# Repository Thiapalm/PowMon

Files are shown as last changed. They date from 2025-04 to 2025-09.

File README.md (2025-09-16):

# (PowMon) Power Monitor Board

<p align=center>
 
 
</p>

This is a hobby development board conceived for usage in my home lab. The device monitors both a shunt  voltage drop and bus supply voltage. Programmable calibration value, conversion times, and averaging,  combined with an internal multiplier, enable direct readouts of current in amperes and power in watts.

The board has 2 headers used for address configuration, allowing all 16 addresses to be used as you see fit. The board power is provided by the I²C connector, and it can be used in 5V or 3V3 modes. 

## License and certification

This is an open source hardware project licensed under CERN-OHL-P. More details on [LICENSE.md](./LICENSE.md).  

## Project

The PCB project was developed in Kicad 9, all necessary project files are available in this repository and can be used freely, according to License.

## Board specifications

The board is based on the [**INA226**](https://www.ti.com/lit/gpn/ina226) from Texas Instruments.  
Board features commonly used in Embedded Systems:
- Measure voltages from 0V up to 36V
- Configurable averaging options
- Reports current, voltage and power
- I²C serial communication (Two Headers for BUS usage)
- LED indicators (LOAD, Board POWER and ALERT)
- 2.7v up to 5v operation voltage from I²C header
- Board Address selector (A0 and A1)

## Board View 

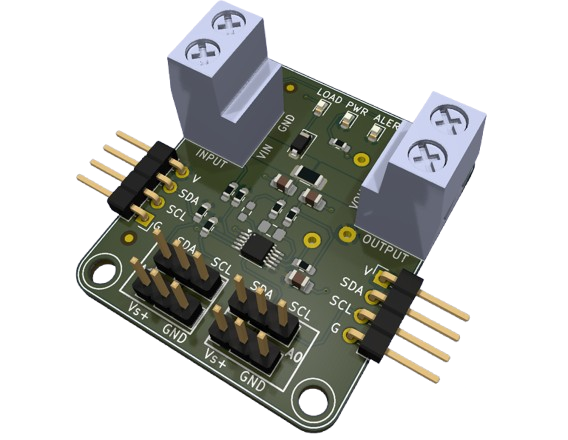
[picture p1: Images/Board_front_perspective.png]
Front


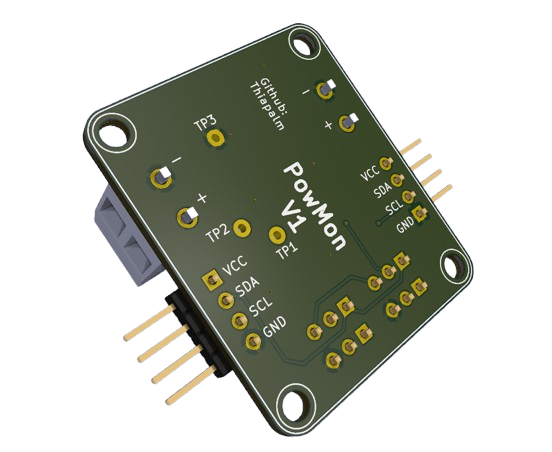
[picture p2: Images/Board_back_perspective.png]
Back


## Board Enclosure 

There is an enclosure made in Freecad 1.0 available on the enclosure folder, it can be used or modified as you see fit. For best results I recommend to print in transparent filament. You will also need 4 M3 x 10mm screws (black with flat head are recommended).  

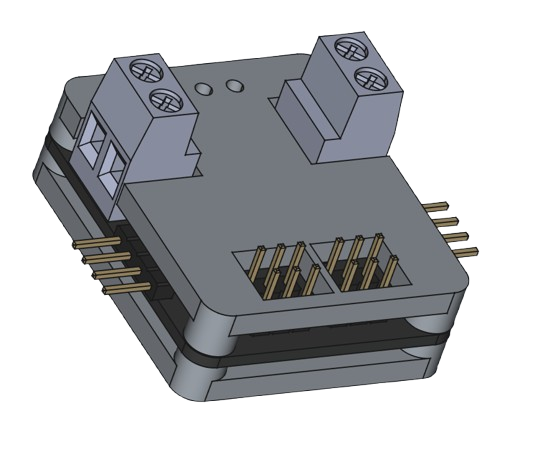
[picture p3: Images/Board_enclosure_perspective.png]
Enclosure

  
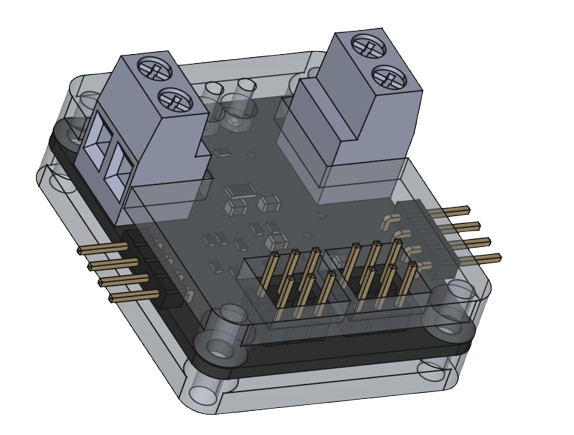
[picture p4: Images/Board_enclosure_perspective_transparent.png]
Transparent


## Version Revision

V1 - current version  
   - Added two I²C headers so it can be used in a bus
   - Added Address configuration headers
   - Added informational LEDs

## Firmware

There is no specific firmware for this board, but i have a driver (crate) developed in RUST for INA226, see it in [crates.io](https://crates.io/crates/ina226-tp) or you can search the internet for a c/c++ version.

## Contribution

Unless you explicitly state otherwise, any contribution intentionally submitted for inclusion in the work by you, as defined in the CERN-OHL-P license, shall be licensed as above, without any additional terms or conditions.

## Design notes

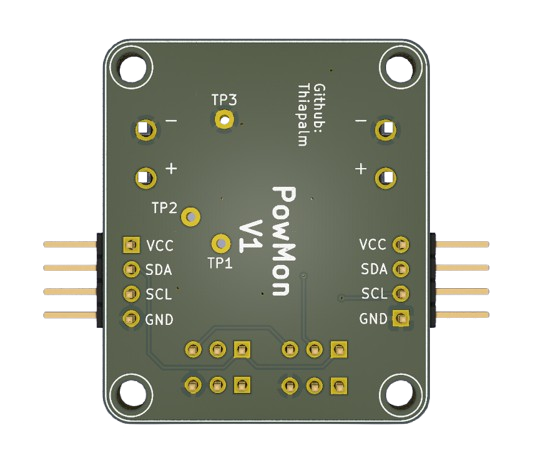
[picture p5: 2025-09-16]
Images/Board_back.png

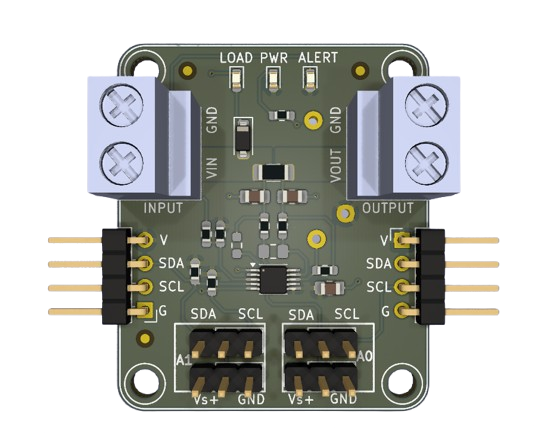
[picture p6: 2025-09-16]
Images/Board_front.png

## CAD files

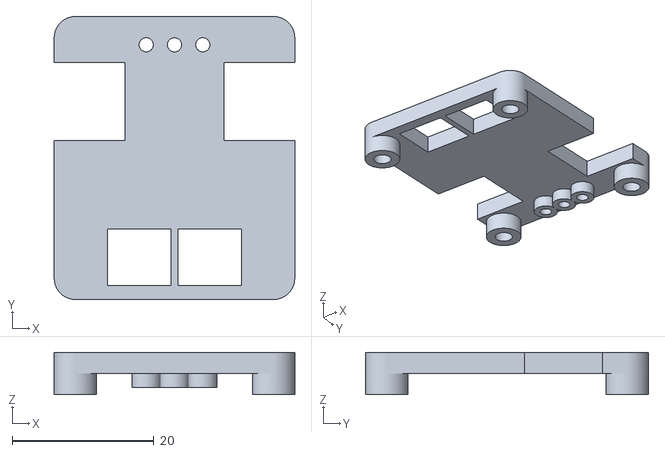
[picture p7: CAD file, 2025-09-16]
enclosure/PowMonBox-TopBody.stl
34.0 x 40.0 x 6.00

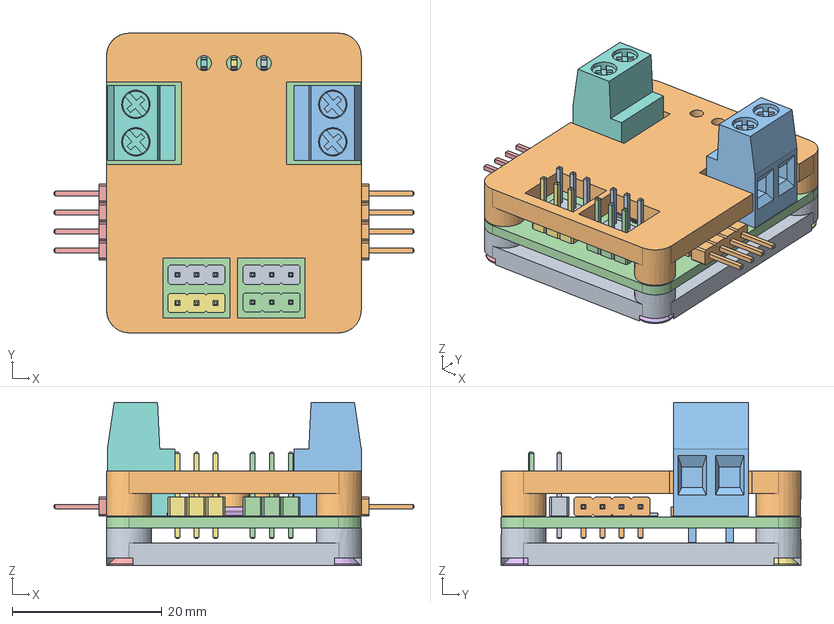
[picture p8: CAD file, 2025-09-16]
enclosure/PowMonBox.FCStd
48.1 x 40.0 x 21.8 mm
PinHeader_1x03_P2.54mm_Vertical
C_0805_2012Metric
R_0603_1608Metric
R_0603_1608Metric001
PinHeader_1x04_P2.54mm_Horizontal
R_0603_1608Metric002
R_1206_3216Metric
2 Way PCB Screw Terminal Block 5mm
LED_0603_1608Metric
R_0603_1608Metric003
2 Way PCB Screw Terminal Block 5mm001
R_0603_1608Metric004
R_0603_1608Metric005
C_0805_2012Metric001
PinHeader_1x03_P2.54mm_Vertical001
LED_0603_1608Metric001
PinHeader_1x03_P2.54mm_Vertical002
C_0805_2012Metric002
D_SOD-123
PinHeader_1x03_P2.54mm_Vertical003
R_0603_1608Metric006
VSSOP-10_3x3mm_P0.5mm
LED_0603_1608Metric002
R_0603_1608Metric007
R_0603_1608Metric008
PinHeader_1x04_P2.54mm_Horizontal001
C_0805_2012Metric003
PowMon_PCB
screw1
screw2
screw3
screw4
BottomBody
TopBody

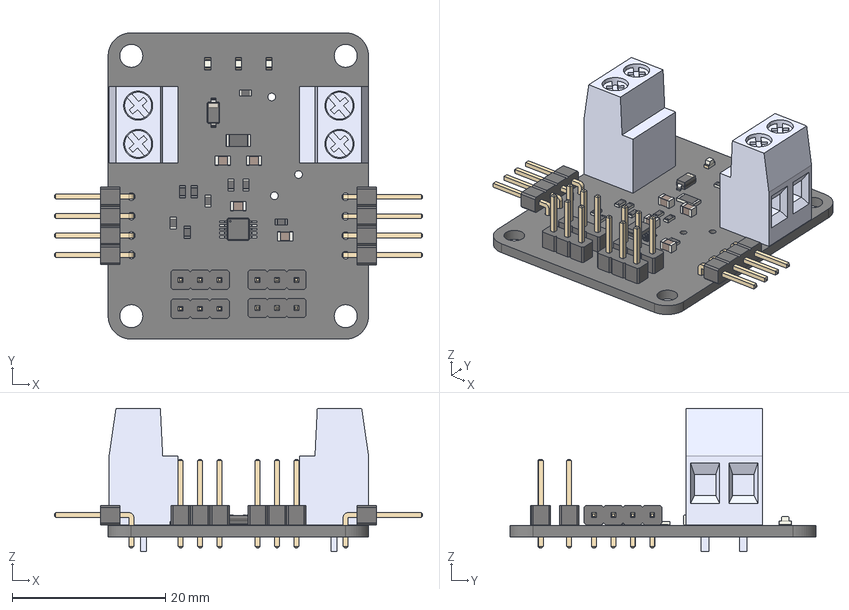
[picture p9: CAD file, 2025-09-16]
STEP/PowMon.step
48.1 x 40.0 x 18.7 mm
PinHeader_1x03_P2.54mm_Vertical x 4
C_0805_2012Metric x 4
R_0603_1608Metric x 9
PinHeader_1x04_P2.54mm_Horizontal x 2
R_1206_3216Metric
2 Way PCB Screw Terminal Block 5mm x 2
LED_0603_1608Metric x 3
D_SOD-123
VSSOP-10_3x3mm_P0.5mm
PowMon_PCB

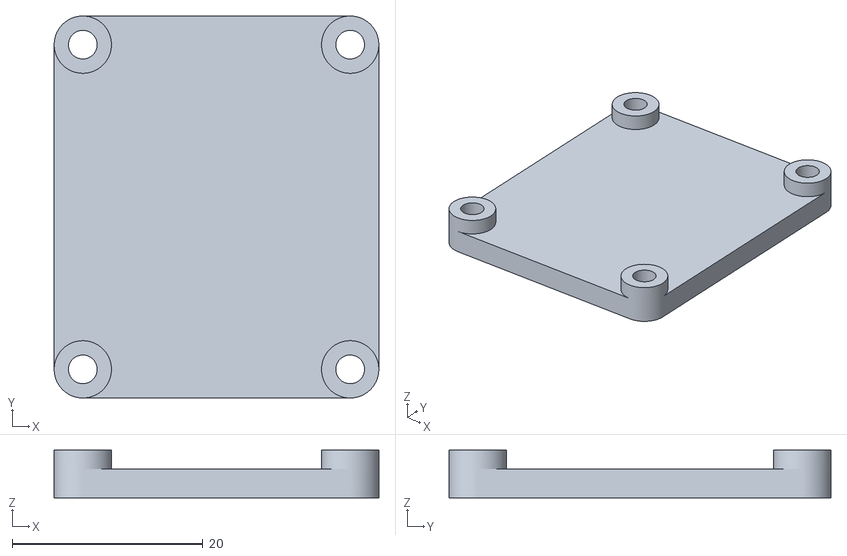
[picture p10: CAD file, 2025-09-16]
enclosure/PowMonBox-BottomBody.stl
34.0 x 40.0 x 5.00

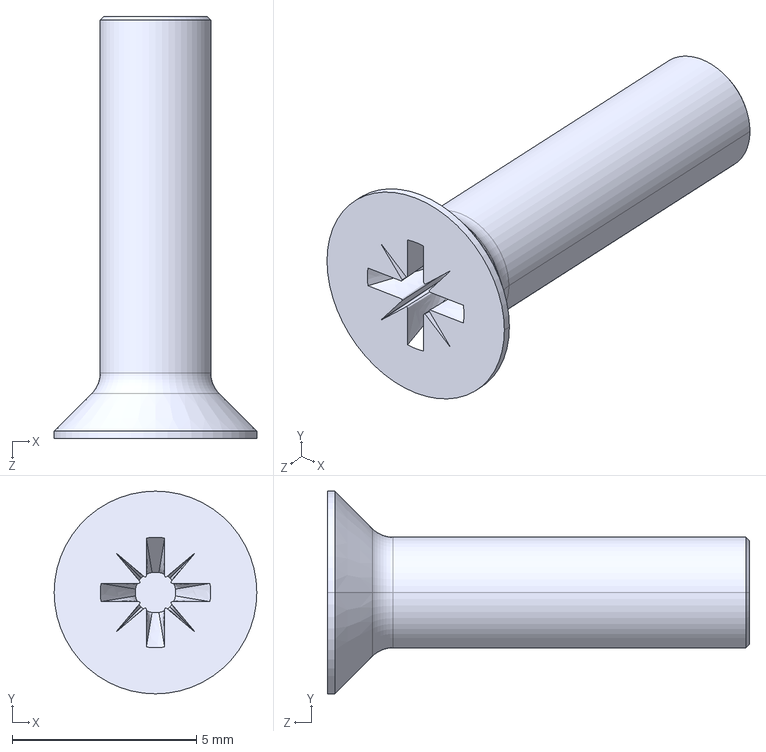
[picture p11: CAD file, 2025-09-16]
STEP/m3-10mm-screw.STEP
5.50 x 5.50 x 11.5 mm

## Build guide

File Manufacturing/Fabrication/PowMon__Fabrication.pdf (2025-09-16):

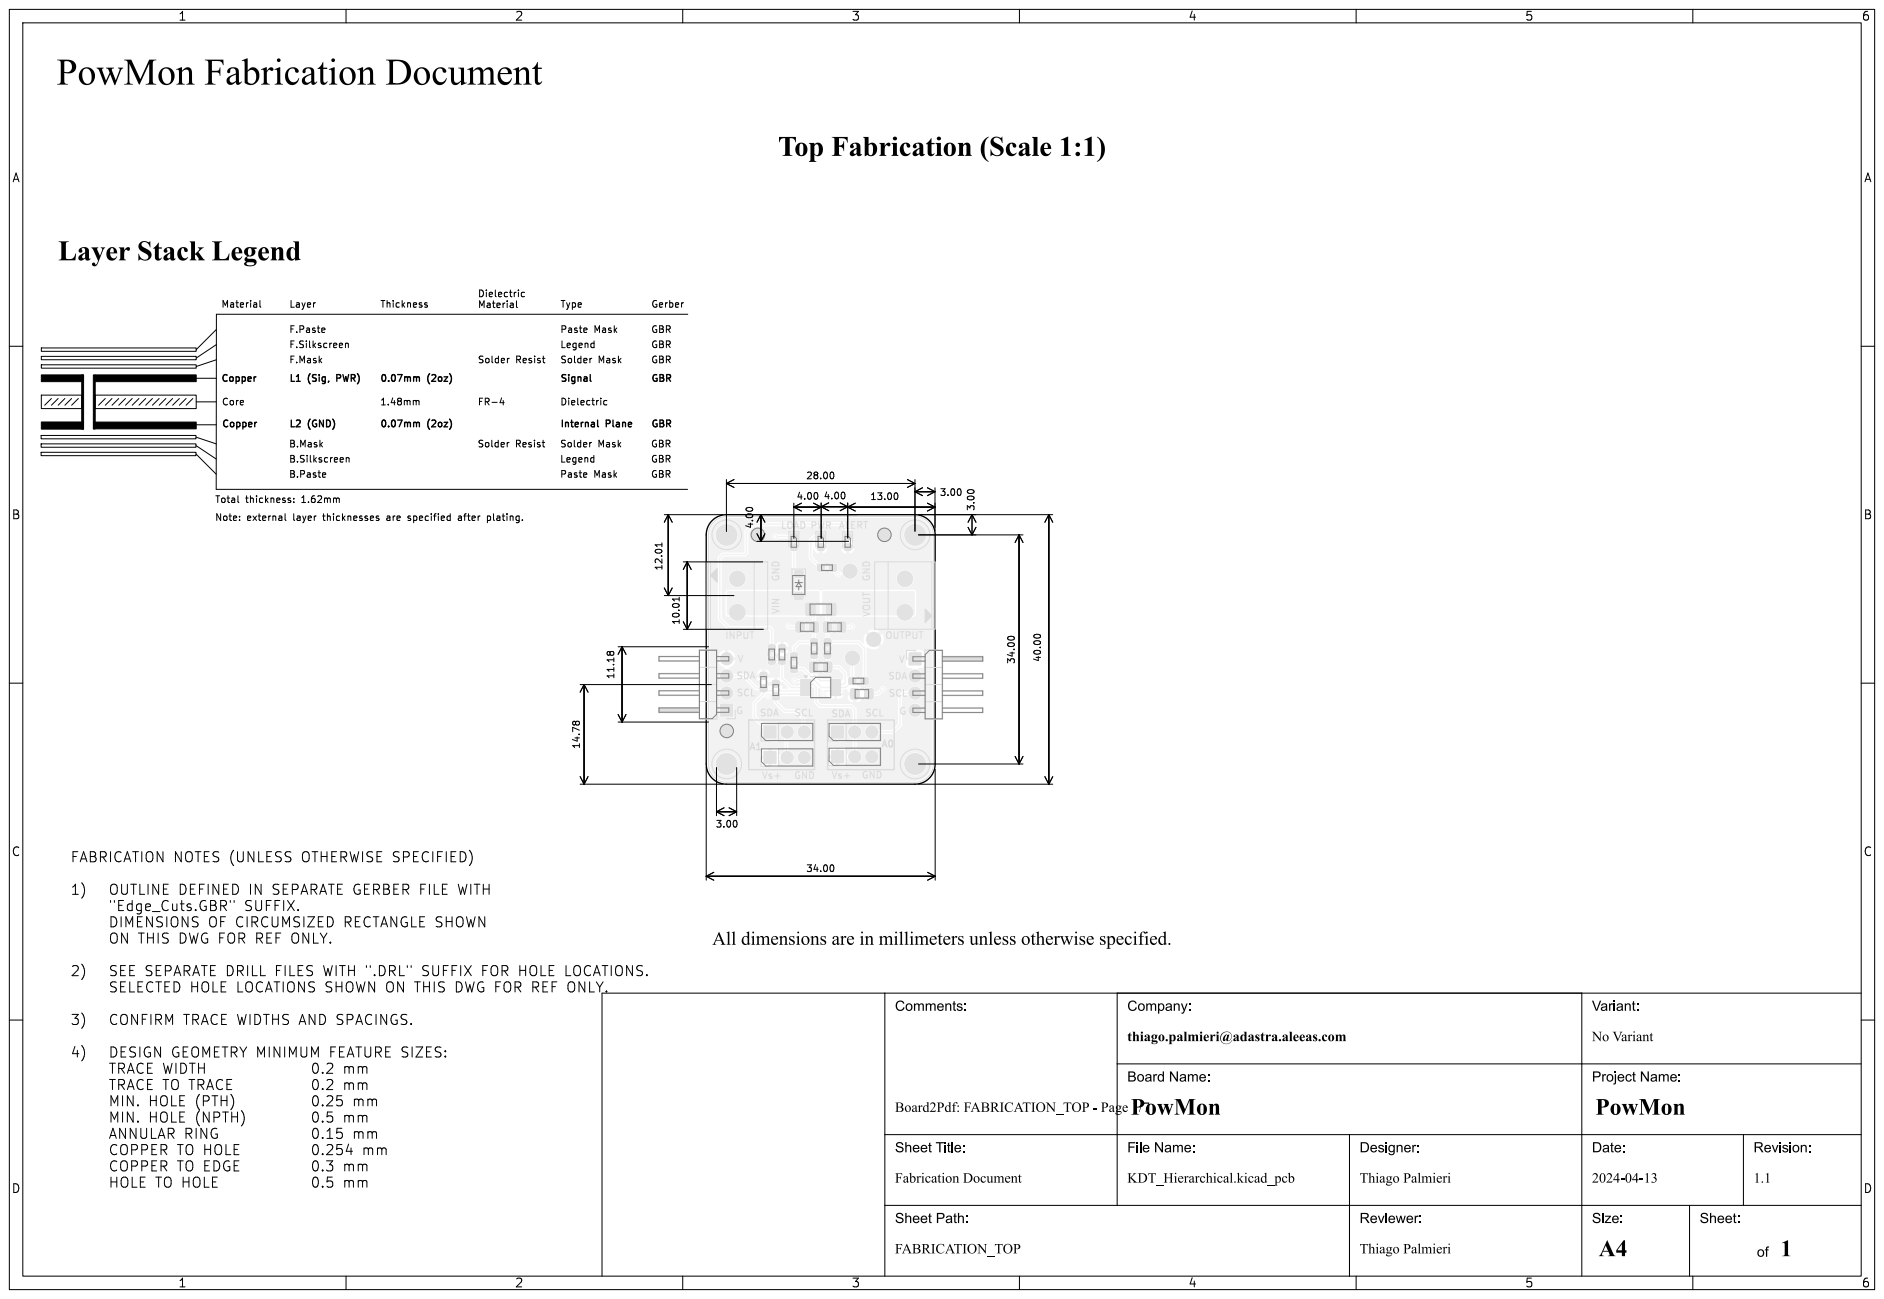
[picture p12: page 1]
LOAD; SCL; A0SDA GND; GND; INPUT SCL; VOUT GND; SDA; Vs+ PWR; SCL ALERT V; VIN; OUTPUT SCL GBR GBR; Total thickness:; Material; FR-4 Solder Resist; GBR; Legend FABRICATION; NOTES (UNLESS OTHERWISE SPECIFIED); 1) OUTLINE; DEFINED IN; SEPARATE; GERBER; FILE; WITH; "Edge_Cuts.GBR"; SUFFIX. DIMENSIONS; OF CIRCUMSIZED; RECTANGLE SHOWN ON; THIS; DWG; FOR; REF ONLY. 2) SEE; DRILL; FILES; ".DRL"; SUFFIX; HOLE LOCATIONS. SELECTED; HOLE; LOCATIONS SHOWN ON; REF ONLY. 3) CONFIRM; TRACE; WIDTHS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

Sheet Path: FabricationDocument Comments: Board2Pdf:FABRICATION_TOP- Page1/7 PowMonFabricationDocument

thiago.palmieri@adastra.aleeas.com

Revision: 1.1 Date: Project Name: 2024-04-13 Reviewer: ThiagoPalmieri Designer:

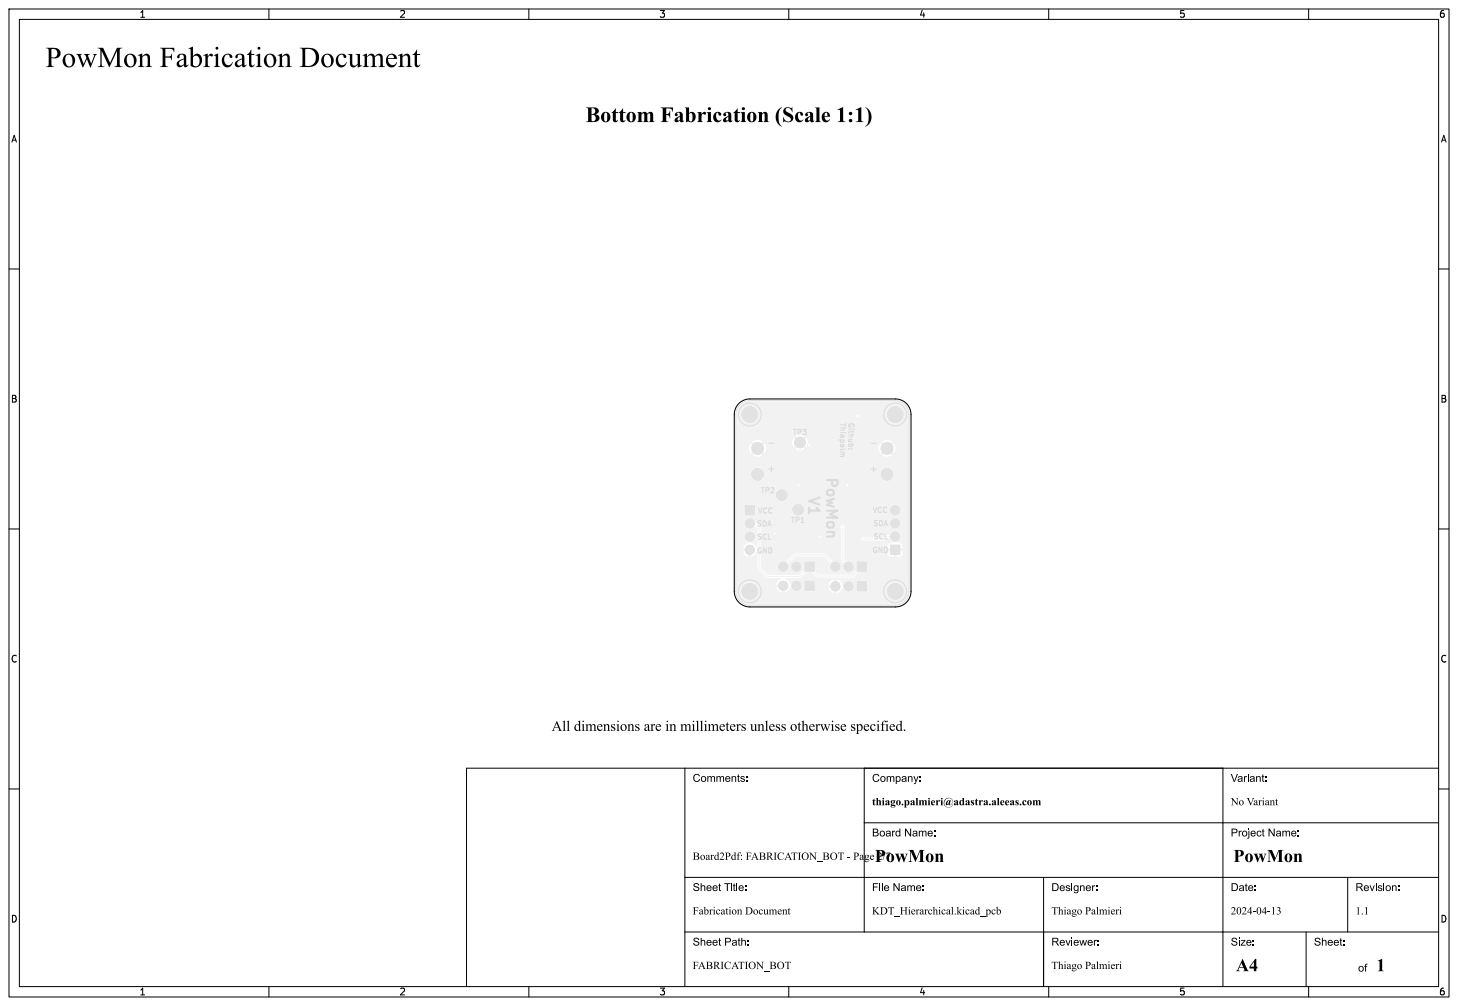
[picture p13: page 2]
SDA; VCC; GND; SCL SDA Thiapalm Github: SCL GND; PowMon; D Sheet: of 1; Size: A4; KDT_Hierarchical.kicad_pcb; ThiagoPalmieri Board Name:; Variant: No Variant Company:; Sheet Title:; File Name: FABRICATION_BOT Sheet Path: FabricationDocument Comments: Board2Pdf:FABRICATION_BOT- Page2/7 PowMonFabricationDocument

thiago.palmieri@adastra.aleeas.com

Revision: 1.1 Date: Project Name: 2024-04-13 Reviewer: ThiagoPalmieri Designer:

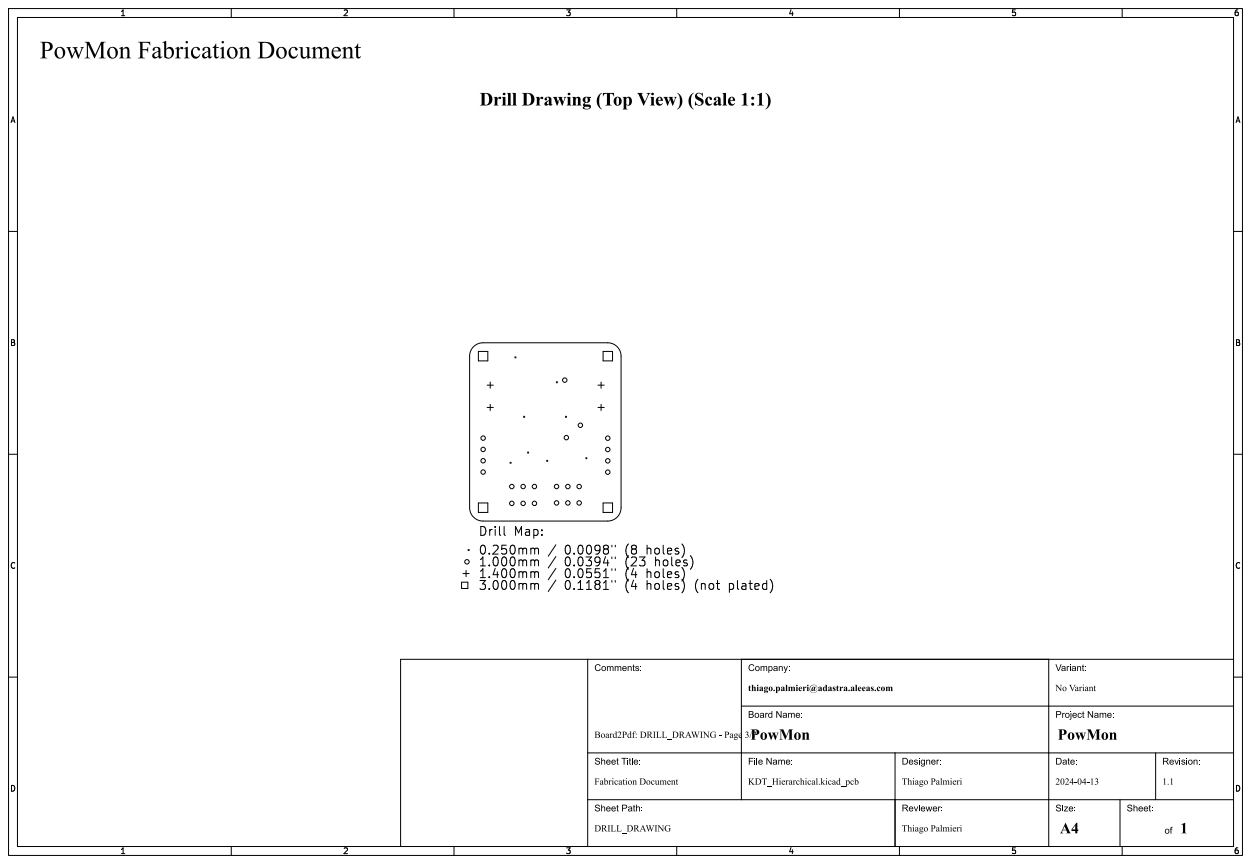
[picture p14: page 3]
D Sheet: of 1; Size: A4; KDT_Hierarchical.kicad_pcb; ThiagoPalmieri Board Name:; Variant: No Variant Company:; PowMon; Sheet Title:; File Name: DRILL_DRAWING

Sheet Path: FabricationDocument Comments: Board2Pdf:DRILL_DRAWING - Page3/7 PowMonFabricationDocument

thiago.palmieri@adastra.aleeas.com

Revision: 1.1 Date: Project Name: 2024-04-13 Reviewer: ThiagoPalmieri Designer:

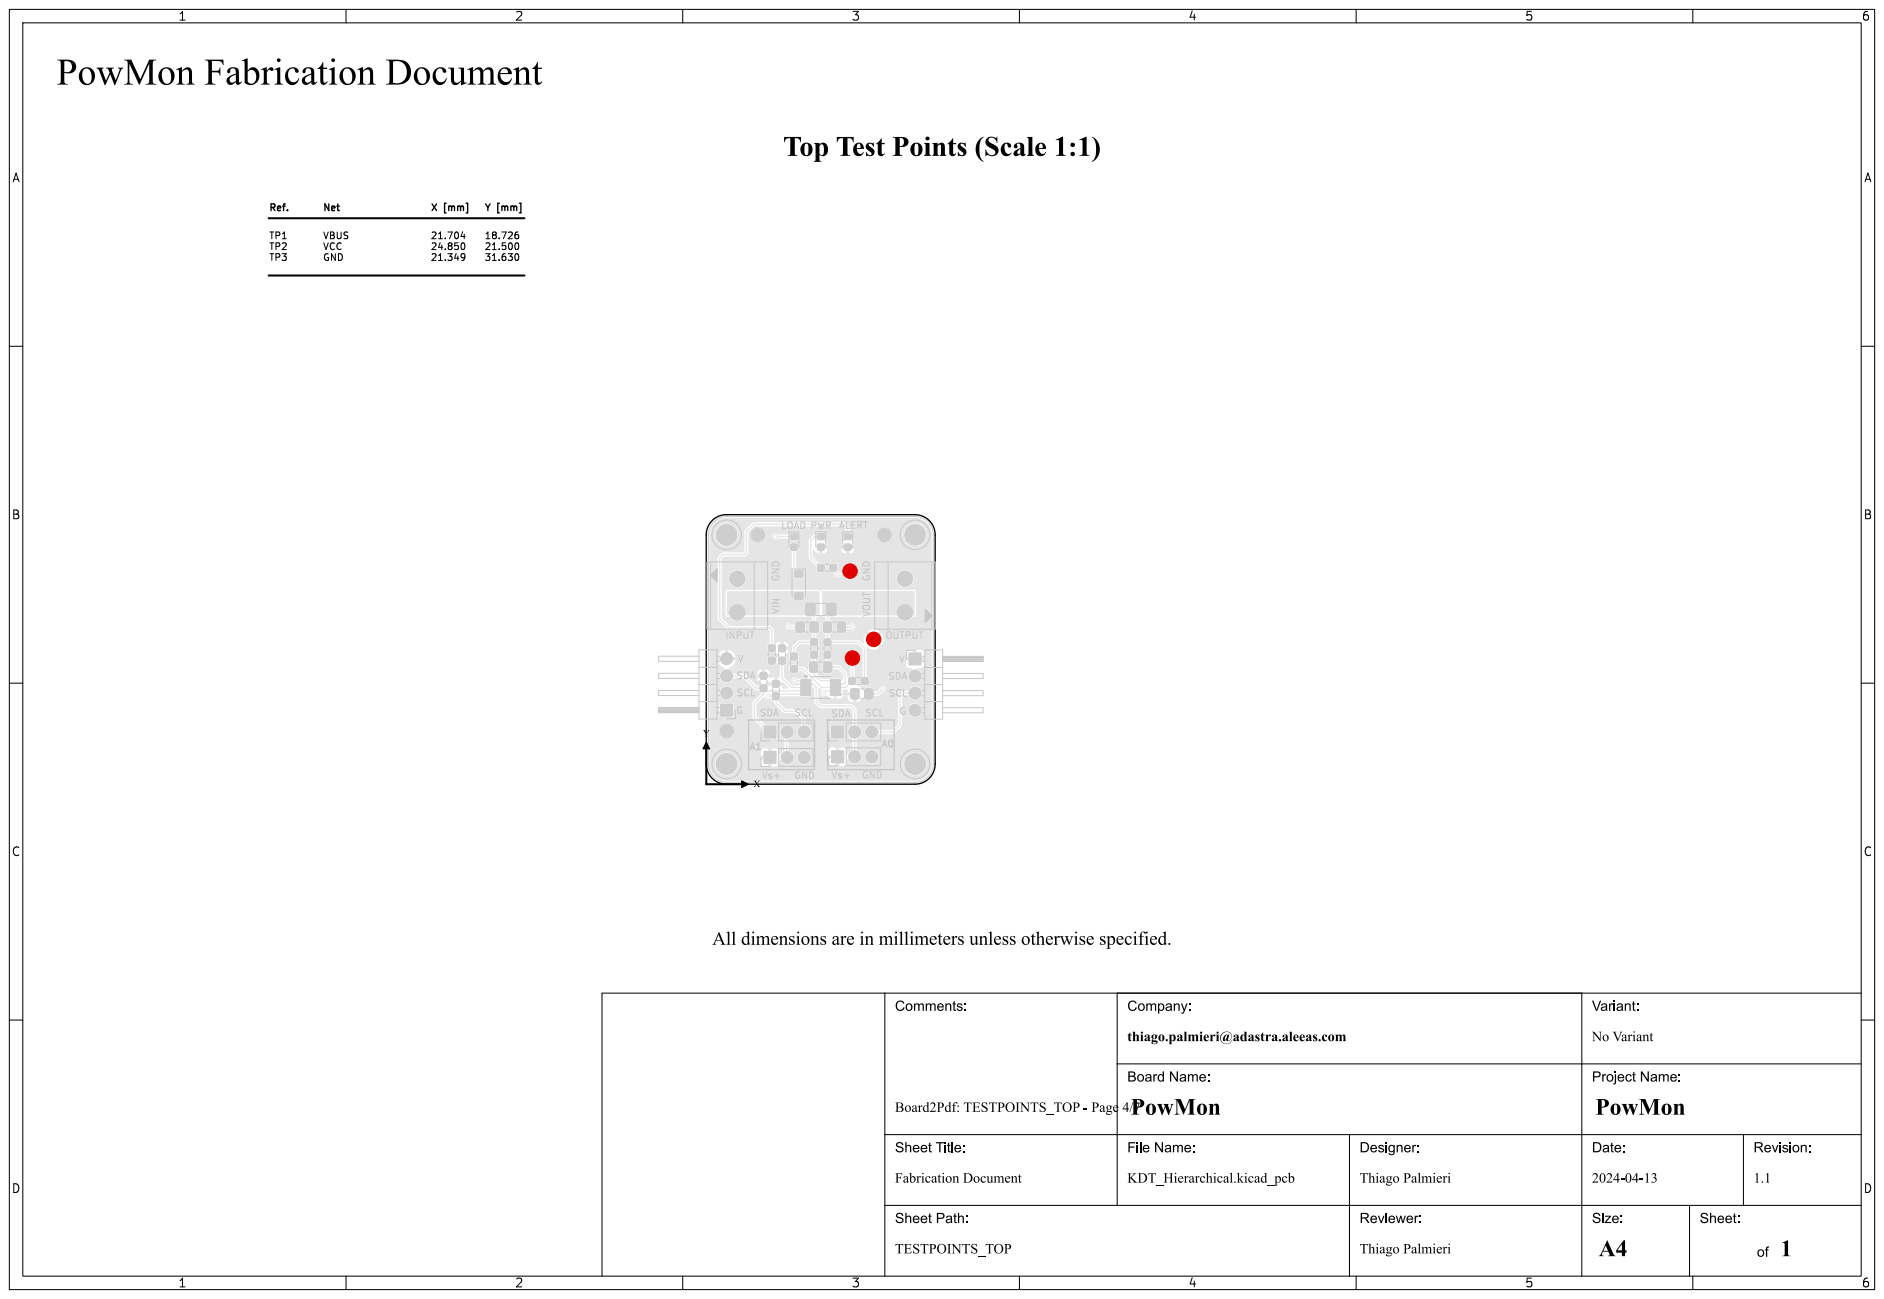
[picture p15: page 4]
LOAD; SCL; A0SDA GND; GND; INPUT SCL; VOUT GND; SDA; Vs+ PWR; SCL ALERT V; VIN; OUTPUT SCL; VBUS VCC GND; 31.630 Ref.; 21.349 Net; D Sheet: of 1; Size: A4; KDT_Hierarchical.kicad_pcb; ThiagoPalmieri Board Name:; Variant: No Variant Company:; PowMon; Sheet Title:; File Name: TESTPOINTS_TOP

Sheet Path: FabricationDocument Comments: Board2Pdf:TESTPOINTS_TOP- Page4/7 PowMonFabricationDocument

thiago.palmieri@adastra.aleeas.com

Revision: 1.1 Date: Project Name: 2024-04-13 Reviewer: ThiagoPalmieri Designer:

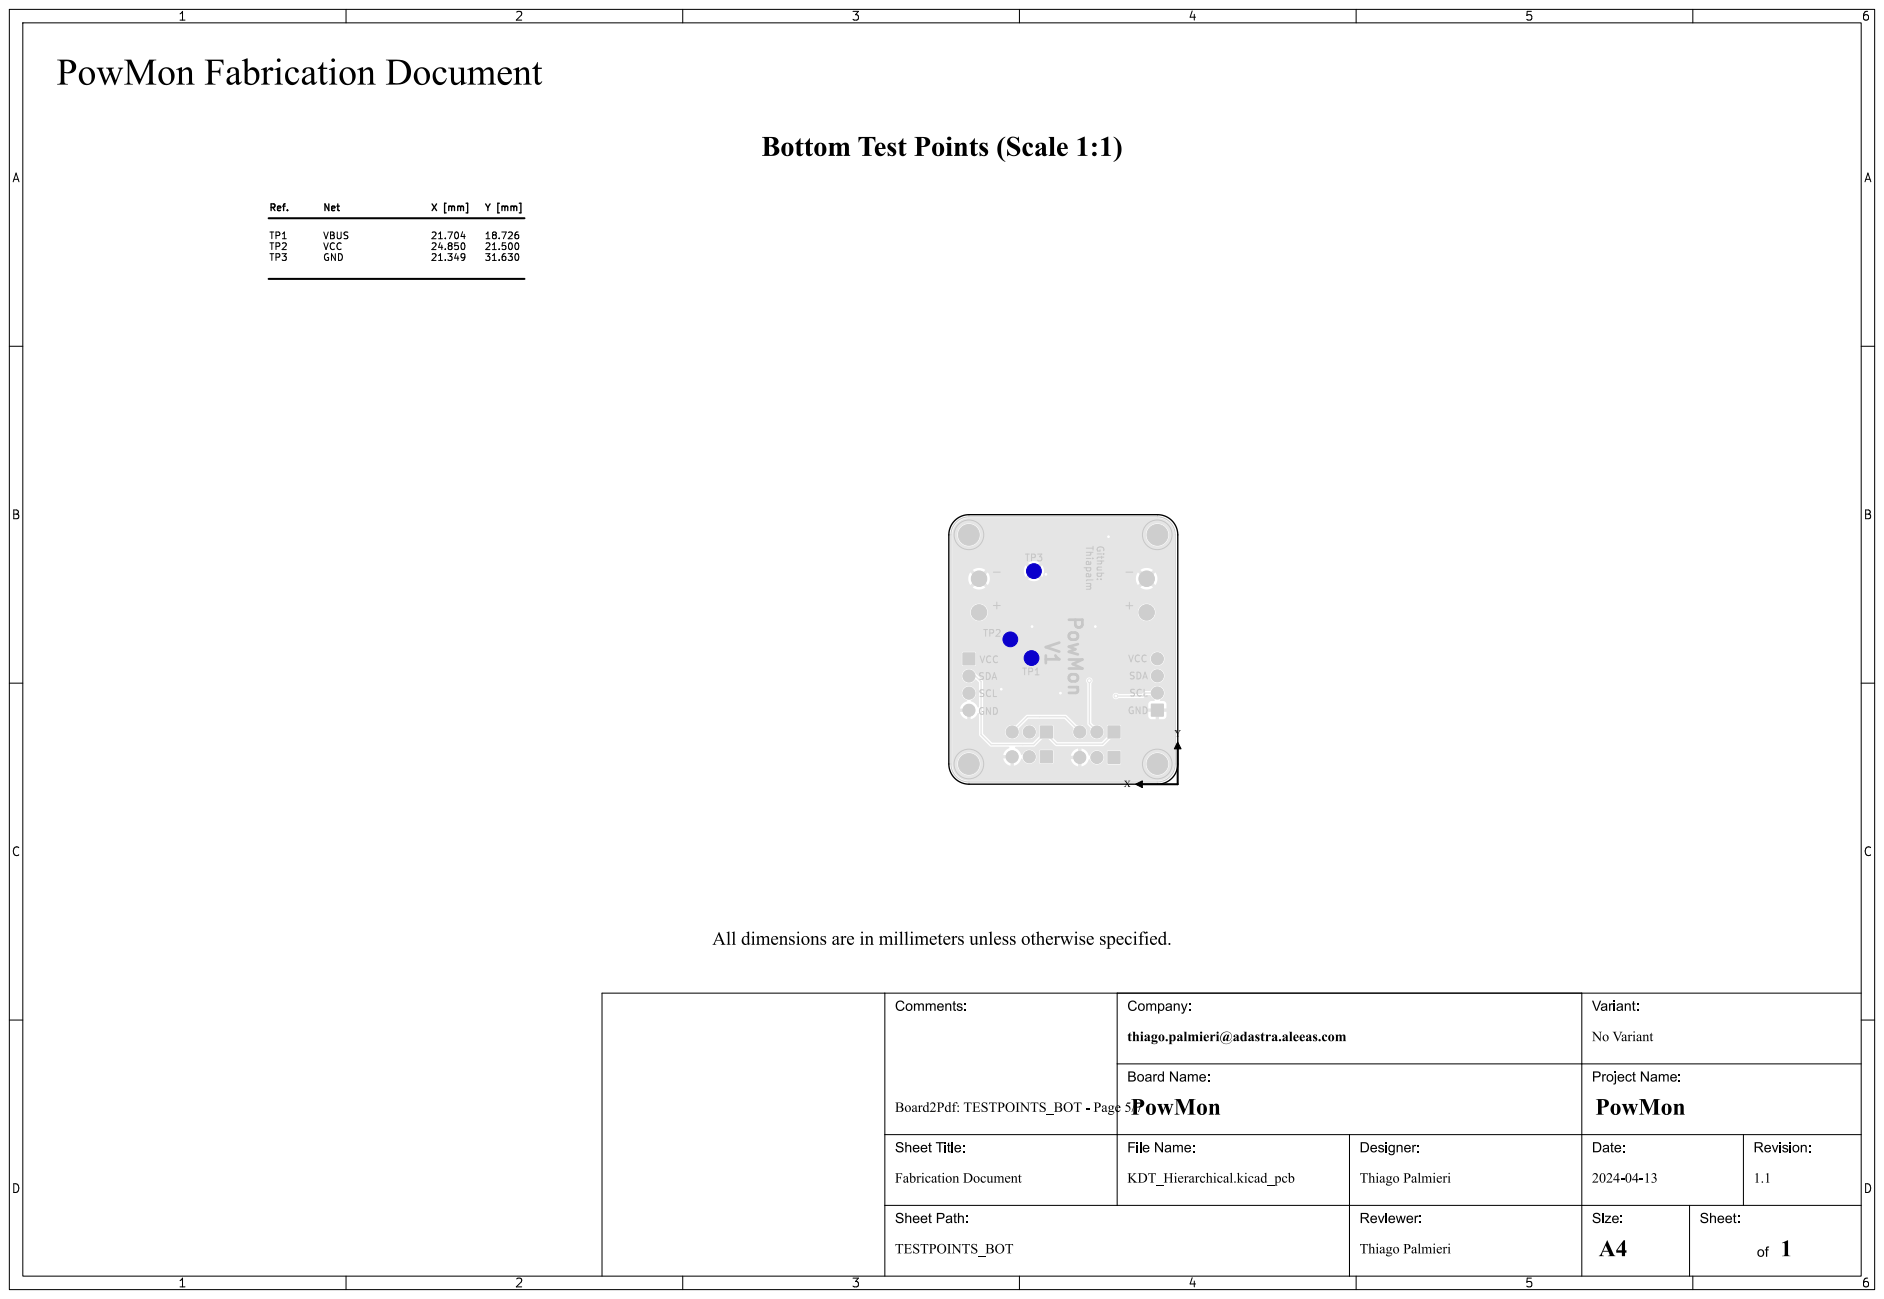
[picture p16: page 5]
SDA; VCC; GND; SCL SDA Thiapalm Github: SCL GND; PowMon; VBUS VCC GND; Net; 31.630 Ref. 1; D Sheet: of 1; Size: A4; KDT_Hierarchical.kicad_pcb; ThiagoPalmieri Board Name:; Variant: No Variant Company:; Sheet Title:; File Name: TESTPOINTS_BOT Sheet Path: FabricationDocument Comments: Board2Pdf:TESTPOINTS_BOT- Page5/7 PowMonFabricationDocument

thiago.palmieri@adastra.aleeas.com

Revision: 1.1 Date: Project Name: 2024-04-13 Reviewer: ThiagoPalmieri Designer:

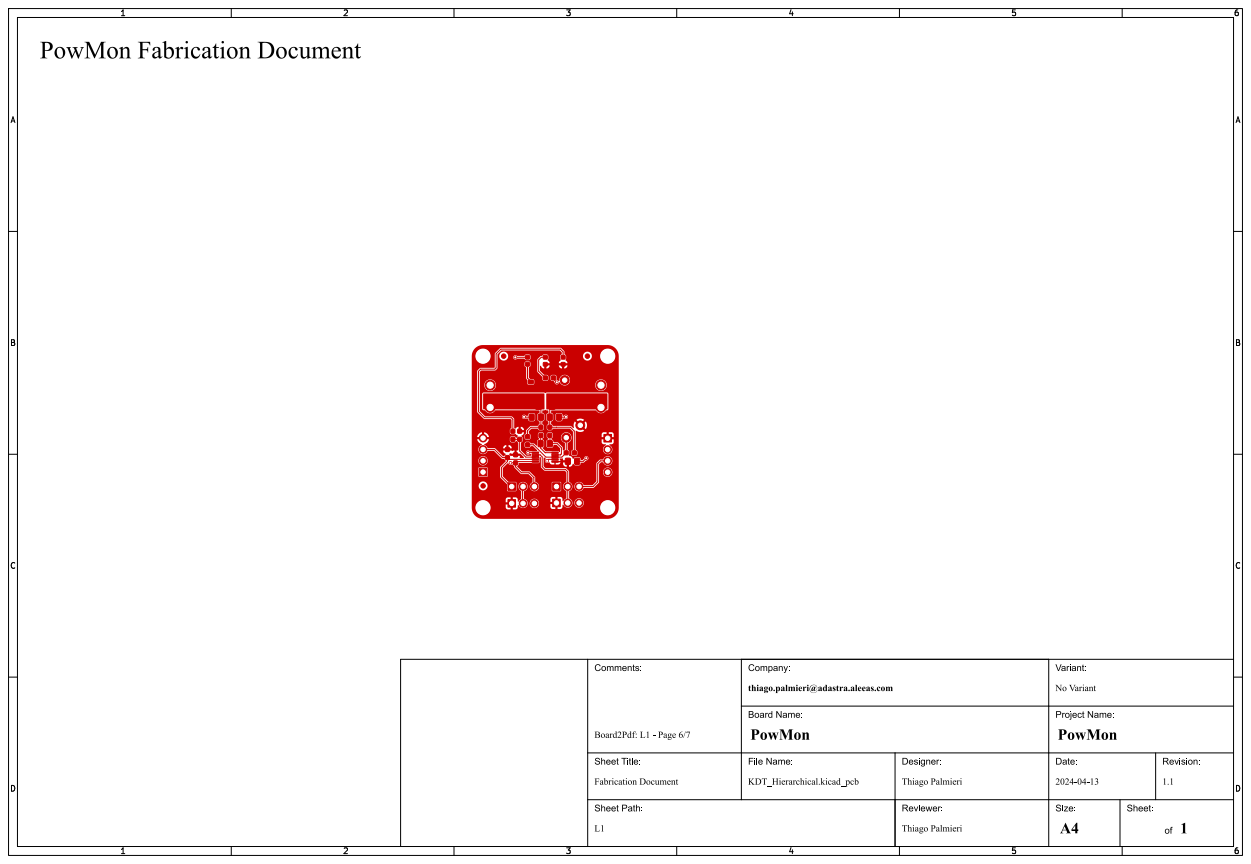
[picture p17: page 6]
D Sheet: of 1; Size: A4; KDT_Hierarchical.kicad_pcb; ThiagoPalmieri Board Name:; Variant: No Variant Company:; PowMon; Sheet Title:; File Name: L1Sheet Path: FabricationDocument Comments: Board2Pdf:L1 - Page6/7 PowMonFabricationDocument

thiago.palmieri@adastra.aleeas.com

Revision: 1.1 Date: Project Name: 2024-04-13 Reviewer: ThiagoPalmieri Designer:

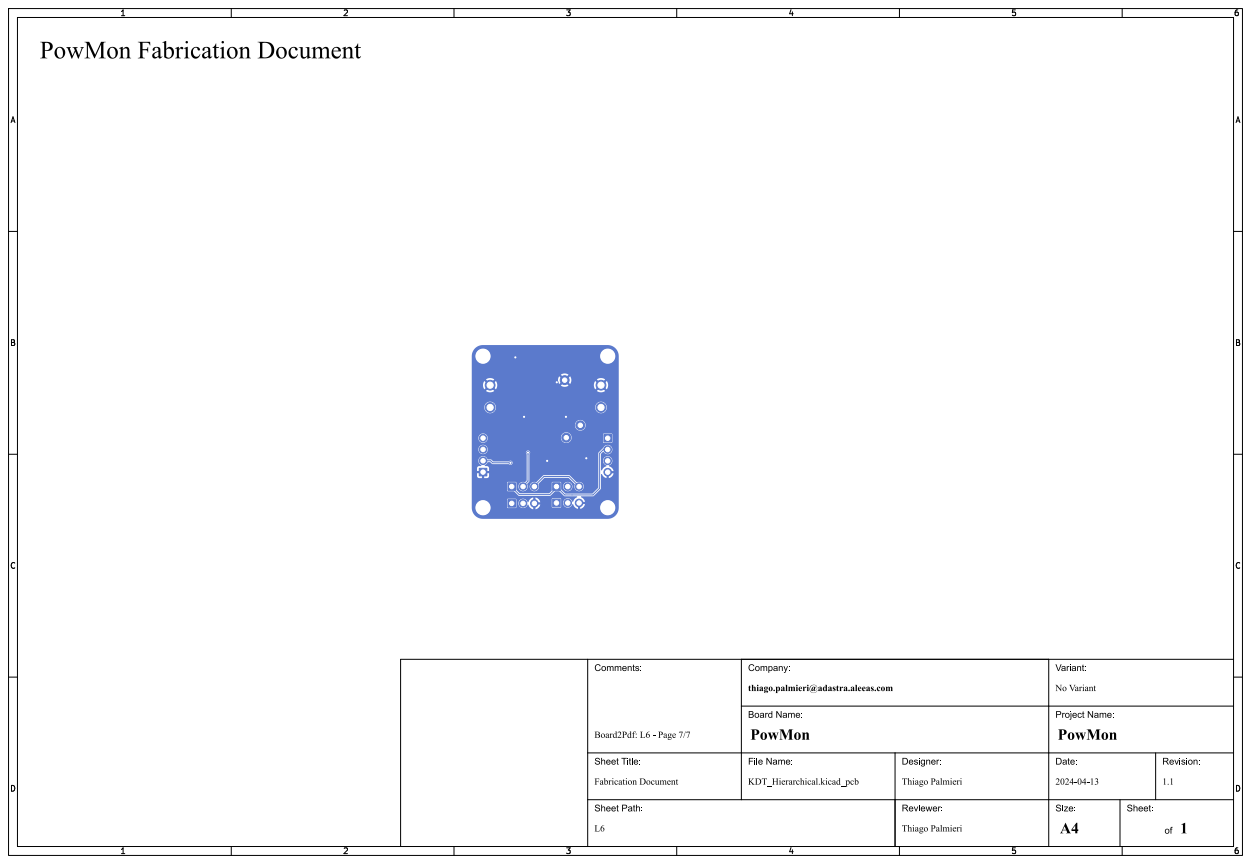
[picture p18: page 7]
D Sheet: of 1; Size: A4; KDT_Hierarchical.kicad_pcb; ThiagoPalmieri Board Name:; Variant: No Variant Company:; PowMon; Sheet Title:; File Name: L6Sheet Path: FabricationDocument Comments: Board2Pdf:L6 - Page7/7 PowMonFabricationDocument

thiago.palmieri@adastra.aleeas.com

Revision: 1.1 Date: Project Name: 2024-04-13 Reviewer: ThiagoPalmieri Designer:

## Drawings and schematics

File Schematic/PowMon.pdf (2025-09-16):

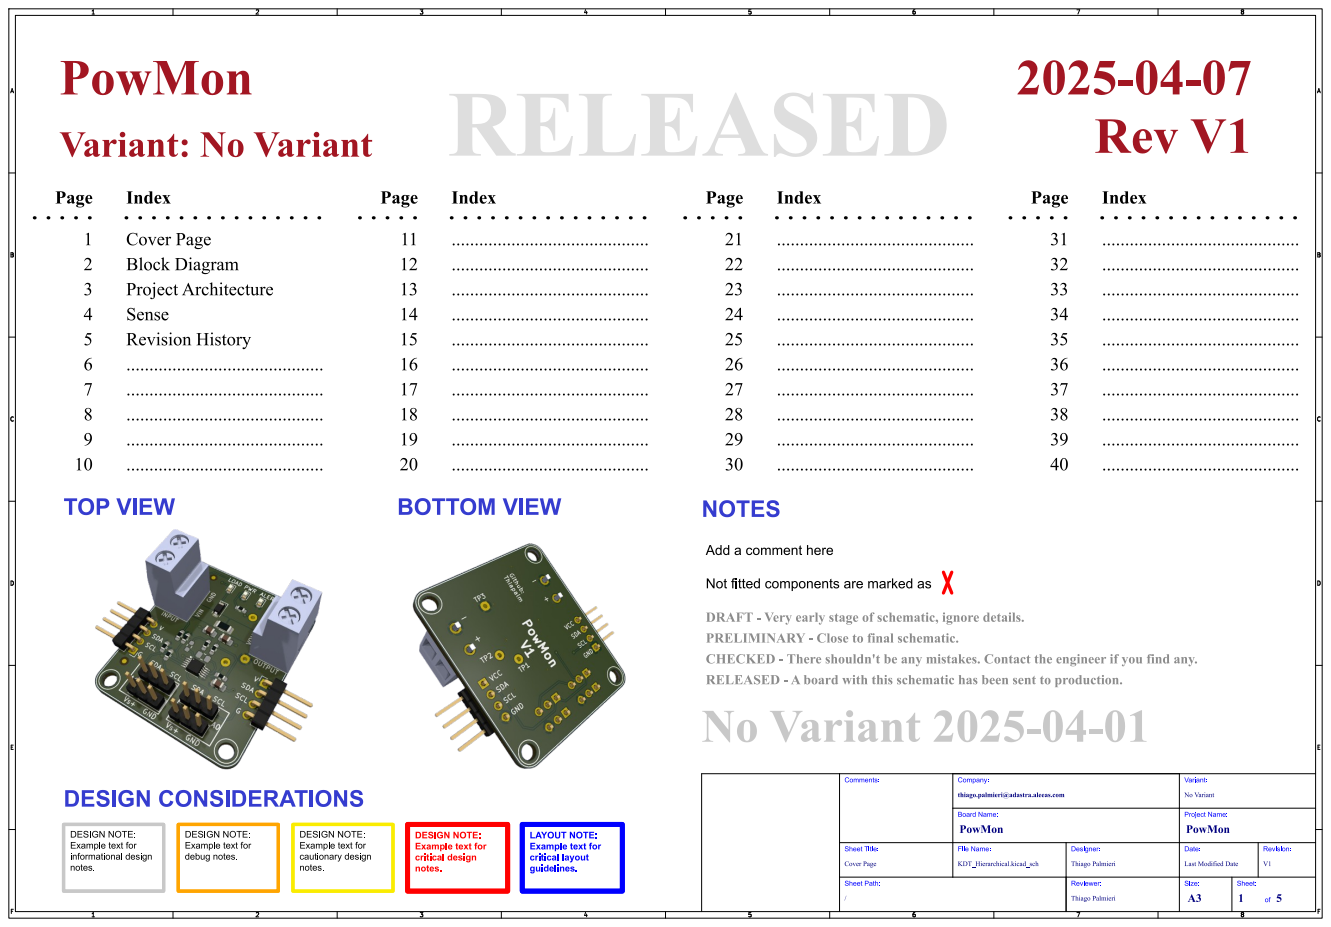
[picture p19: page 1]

Not fitted components are marked as

DRAFT - Veryearlystageof schematic,ignoredetails.
PRELIMINARY - Closetofinal schematic.
CHECKED - Thereshouldn'tbeanymistakes.Contacttheengineerif youfindany.
RELEASED - A boardwiththisschematichasbeensenttoproduction.
NoVariant2025-04-01

thiago.palmieri@adastra.aleeas.com

Revision: V1 Date: Project Name: LastModified Date Reviewer: ThiagoPalmieri Designer:

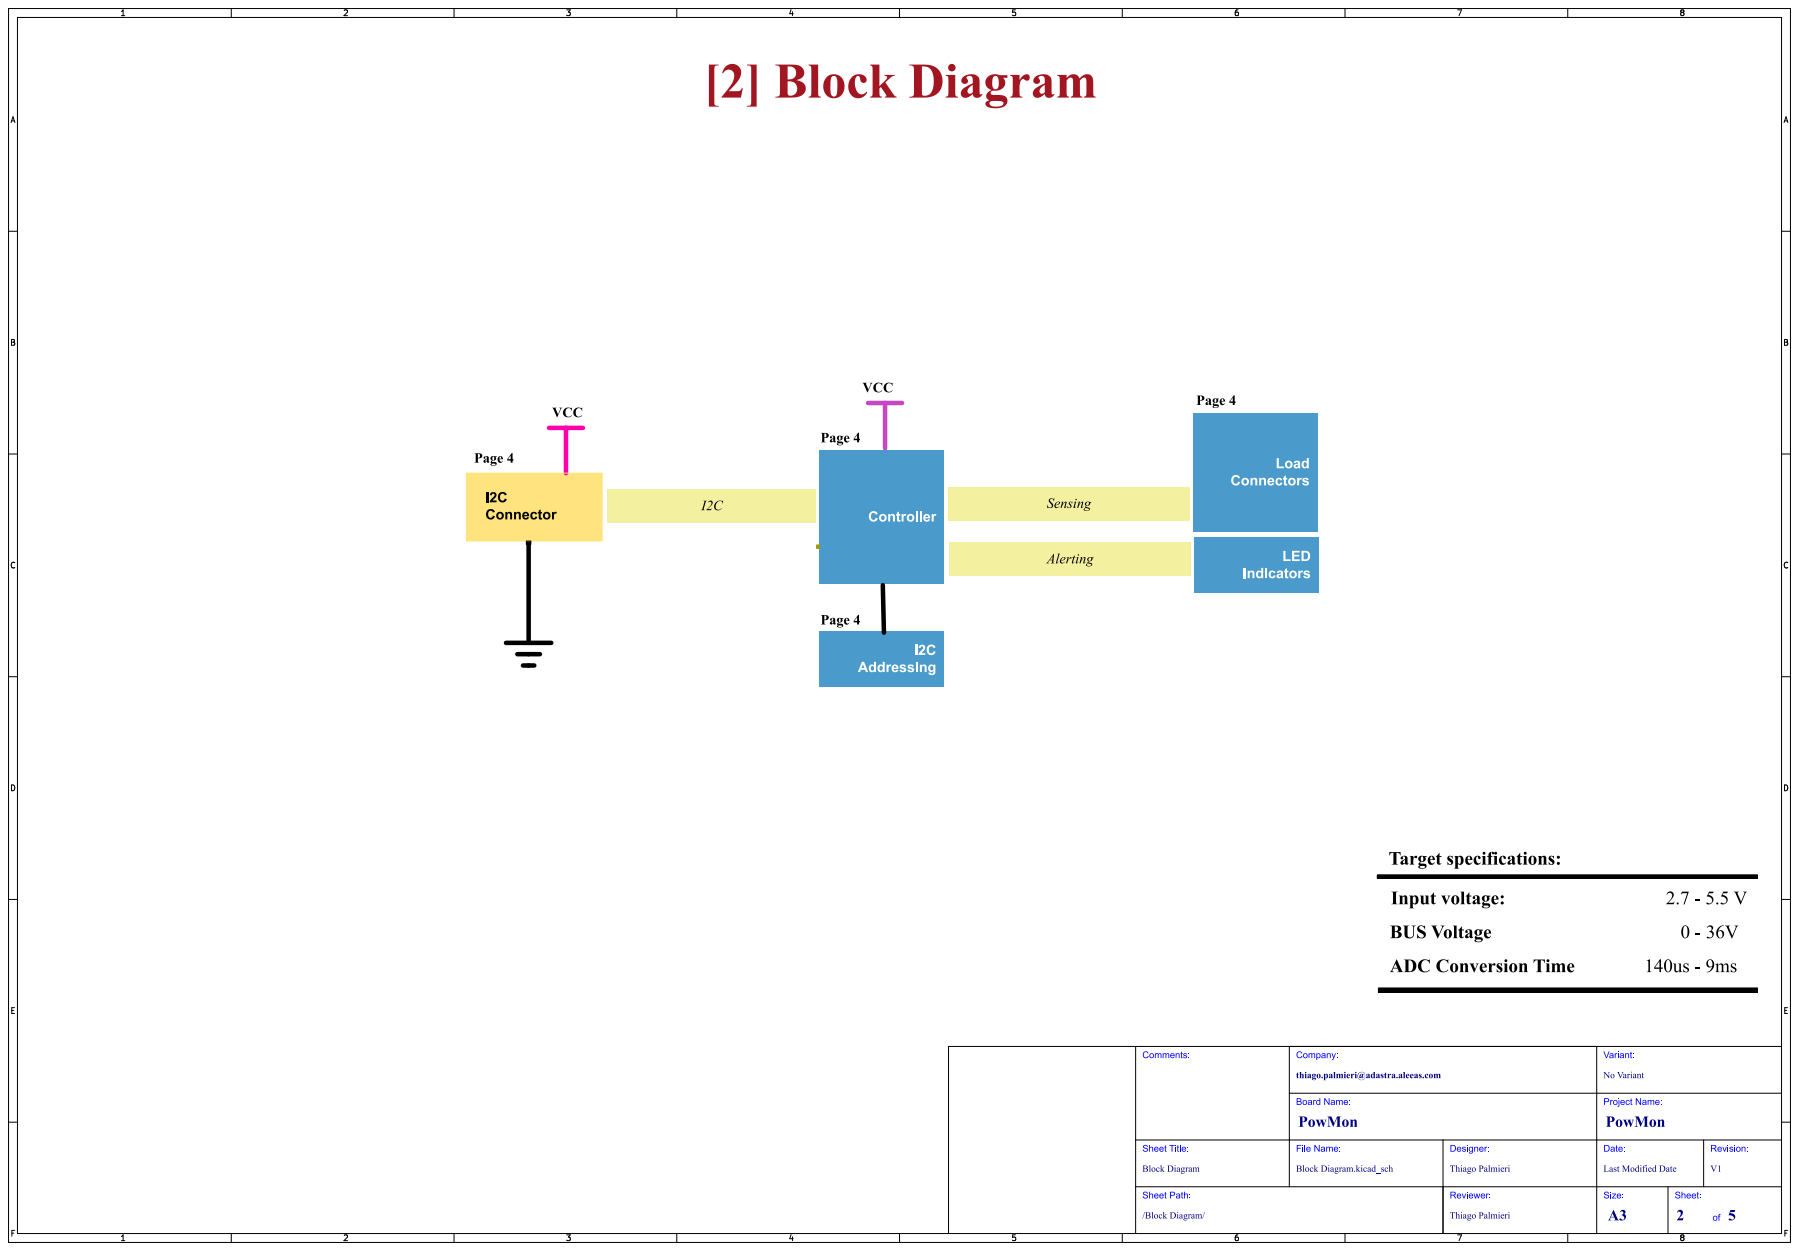
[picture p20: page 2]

thiago.palmieri@adastra.aleeas.com

/Block Diagram/ Sheet Path: Block Diagram

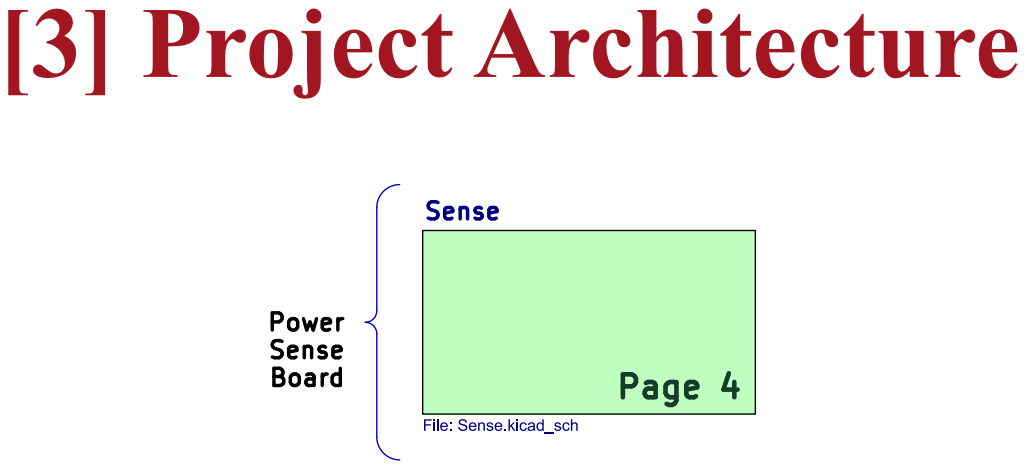
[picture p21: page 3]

/ProjectArchitecture/ Sheet Path: ProjectArchitecture Comments:

thiago.palmieri@adastra.aleeas.com

Revision: V1 Date: Project Name: LastModified Date Reviewer: ThiagoPalmieri Designer:

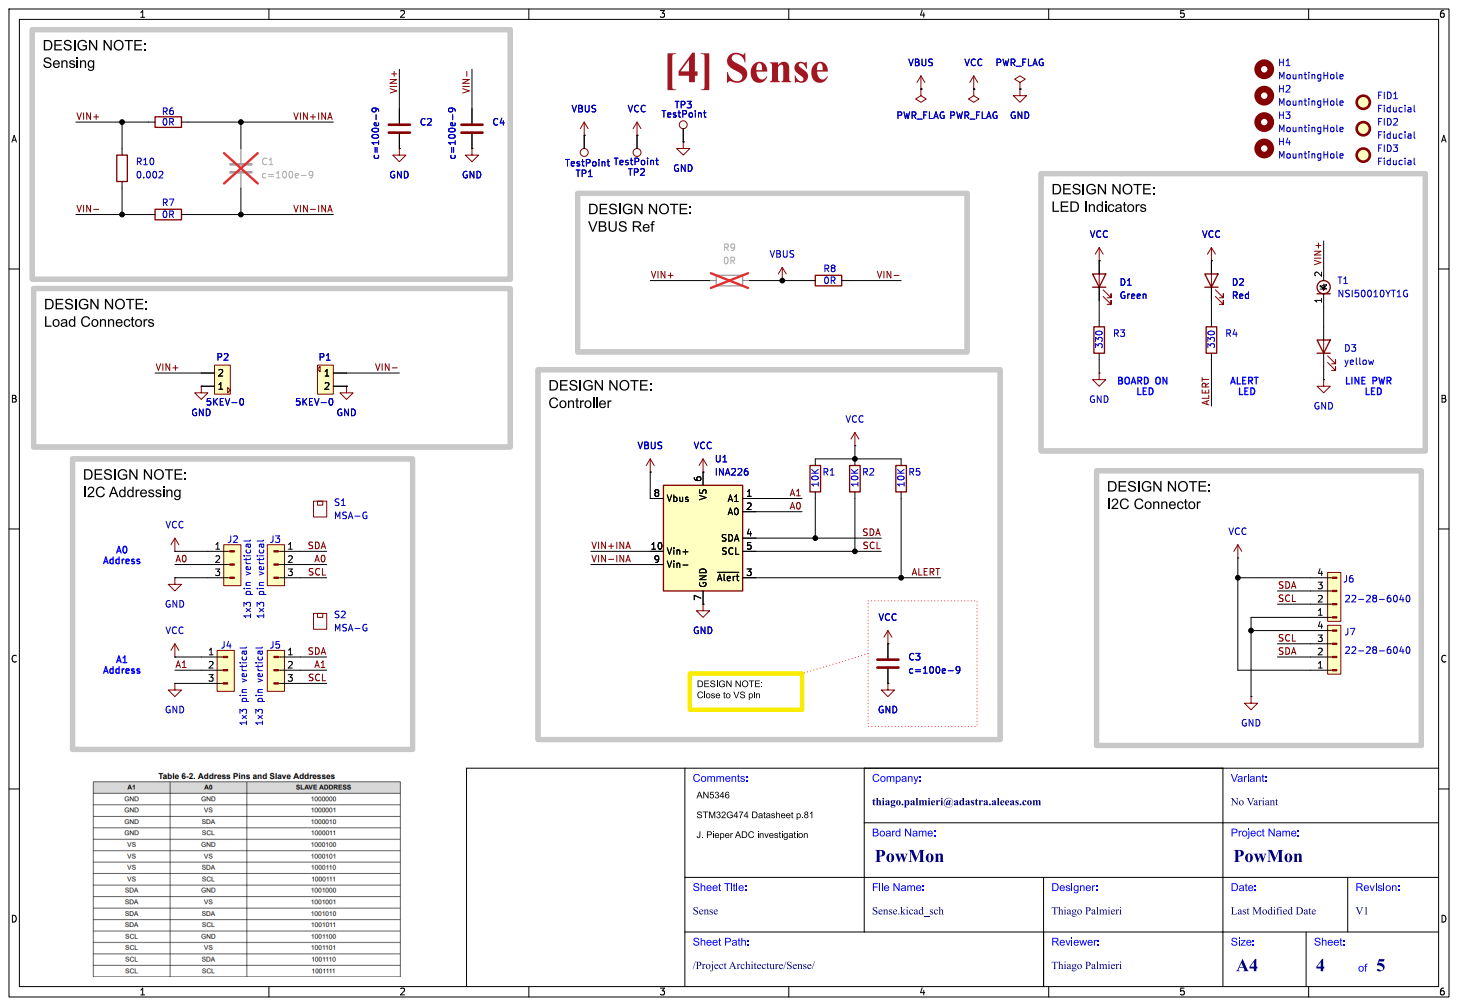
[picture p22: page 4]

7 A1 1 A0 2 SDA 4 SCL 5 ~{Alert}3 VCC GND

/ProjectArchitecture/Sense/ Sheet Path: Sense Comments:

thiago.palmieri@adastra.aleeas.com

Revision: V1 Date: Project Name: LastModified Date Reviewer: ThiagoPalmieri Designer:

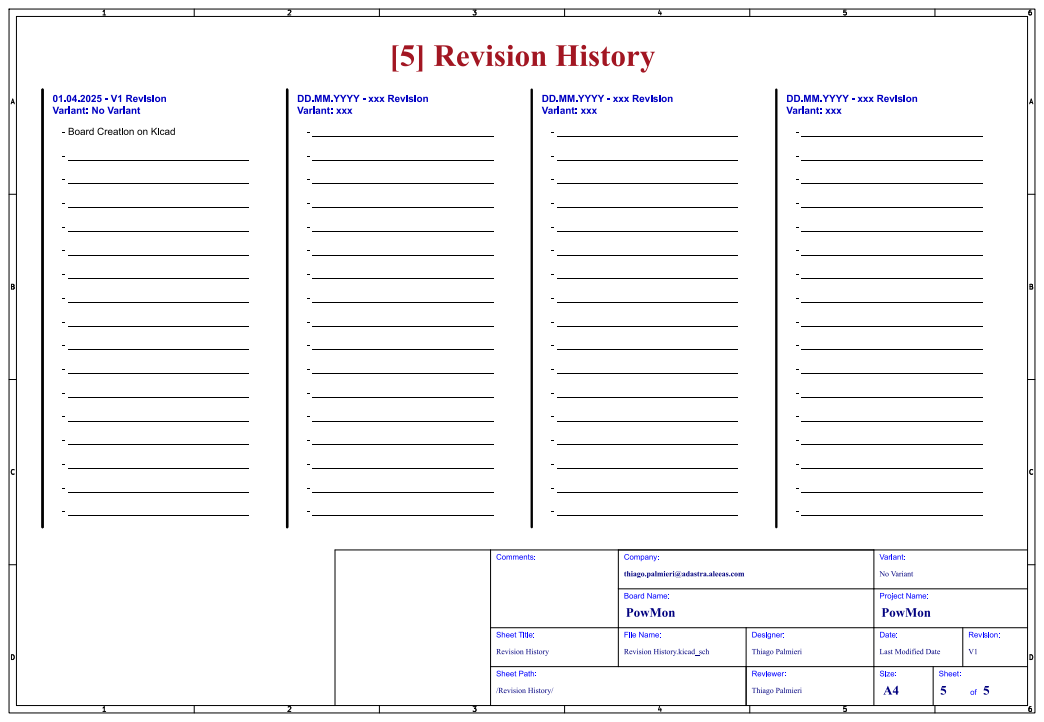
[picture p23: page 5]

01.04.2025 - V1 Revision
Variant: No Variant
- Board Creation on Kicad

Variant: xxx DD.MM.YYYY - xxx Revision

DD.MM.YYYY - xxx Revision

/RevisionHistory/ Sheet Path: RevisionHistory Comments:

thiago.palmieri@adastra.aleeas.com

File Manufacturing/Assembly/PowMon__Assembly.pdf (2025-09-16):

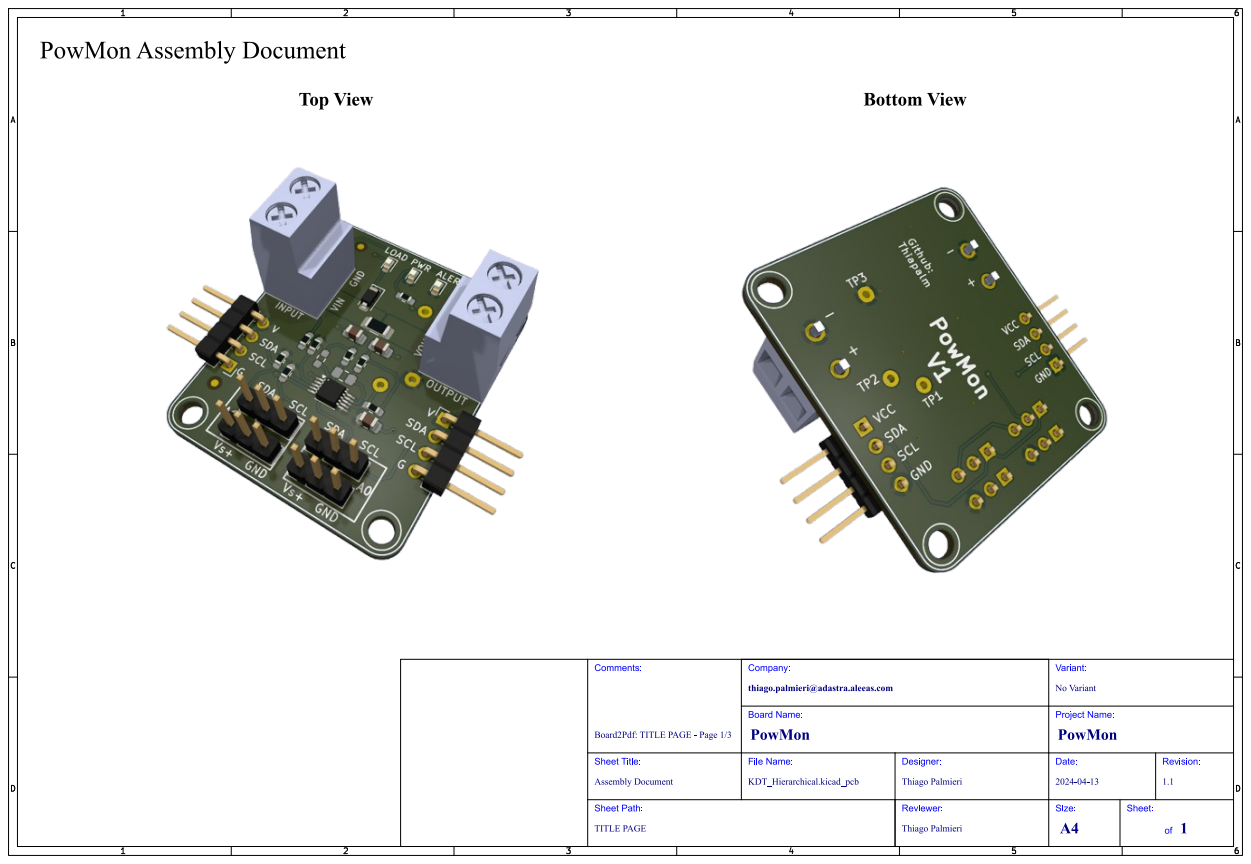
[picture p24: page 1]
D Sheet: of 1; Size: A4; KDT_Hierarchical.kicad_pcb; ThiagoPalmieri Board Name:; Variant: No Variant Company:; PowMon; Sheet Title:; File Name: TITLE PAGE

Sheet Path: AssemblyDocument Comments: Board2Pdf:TITLE PAGE- Page1/3 PowMonAssemblyDocument

thiago.palmieri@adastra.aleeas.com

Revision: 1.1 Date: Project Name: 2024-04-13 Reviewer: ThiagoPalmieri Designer:

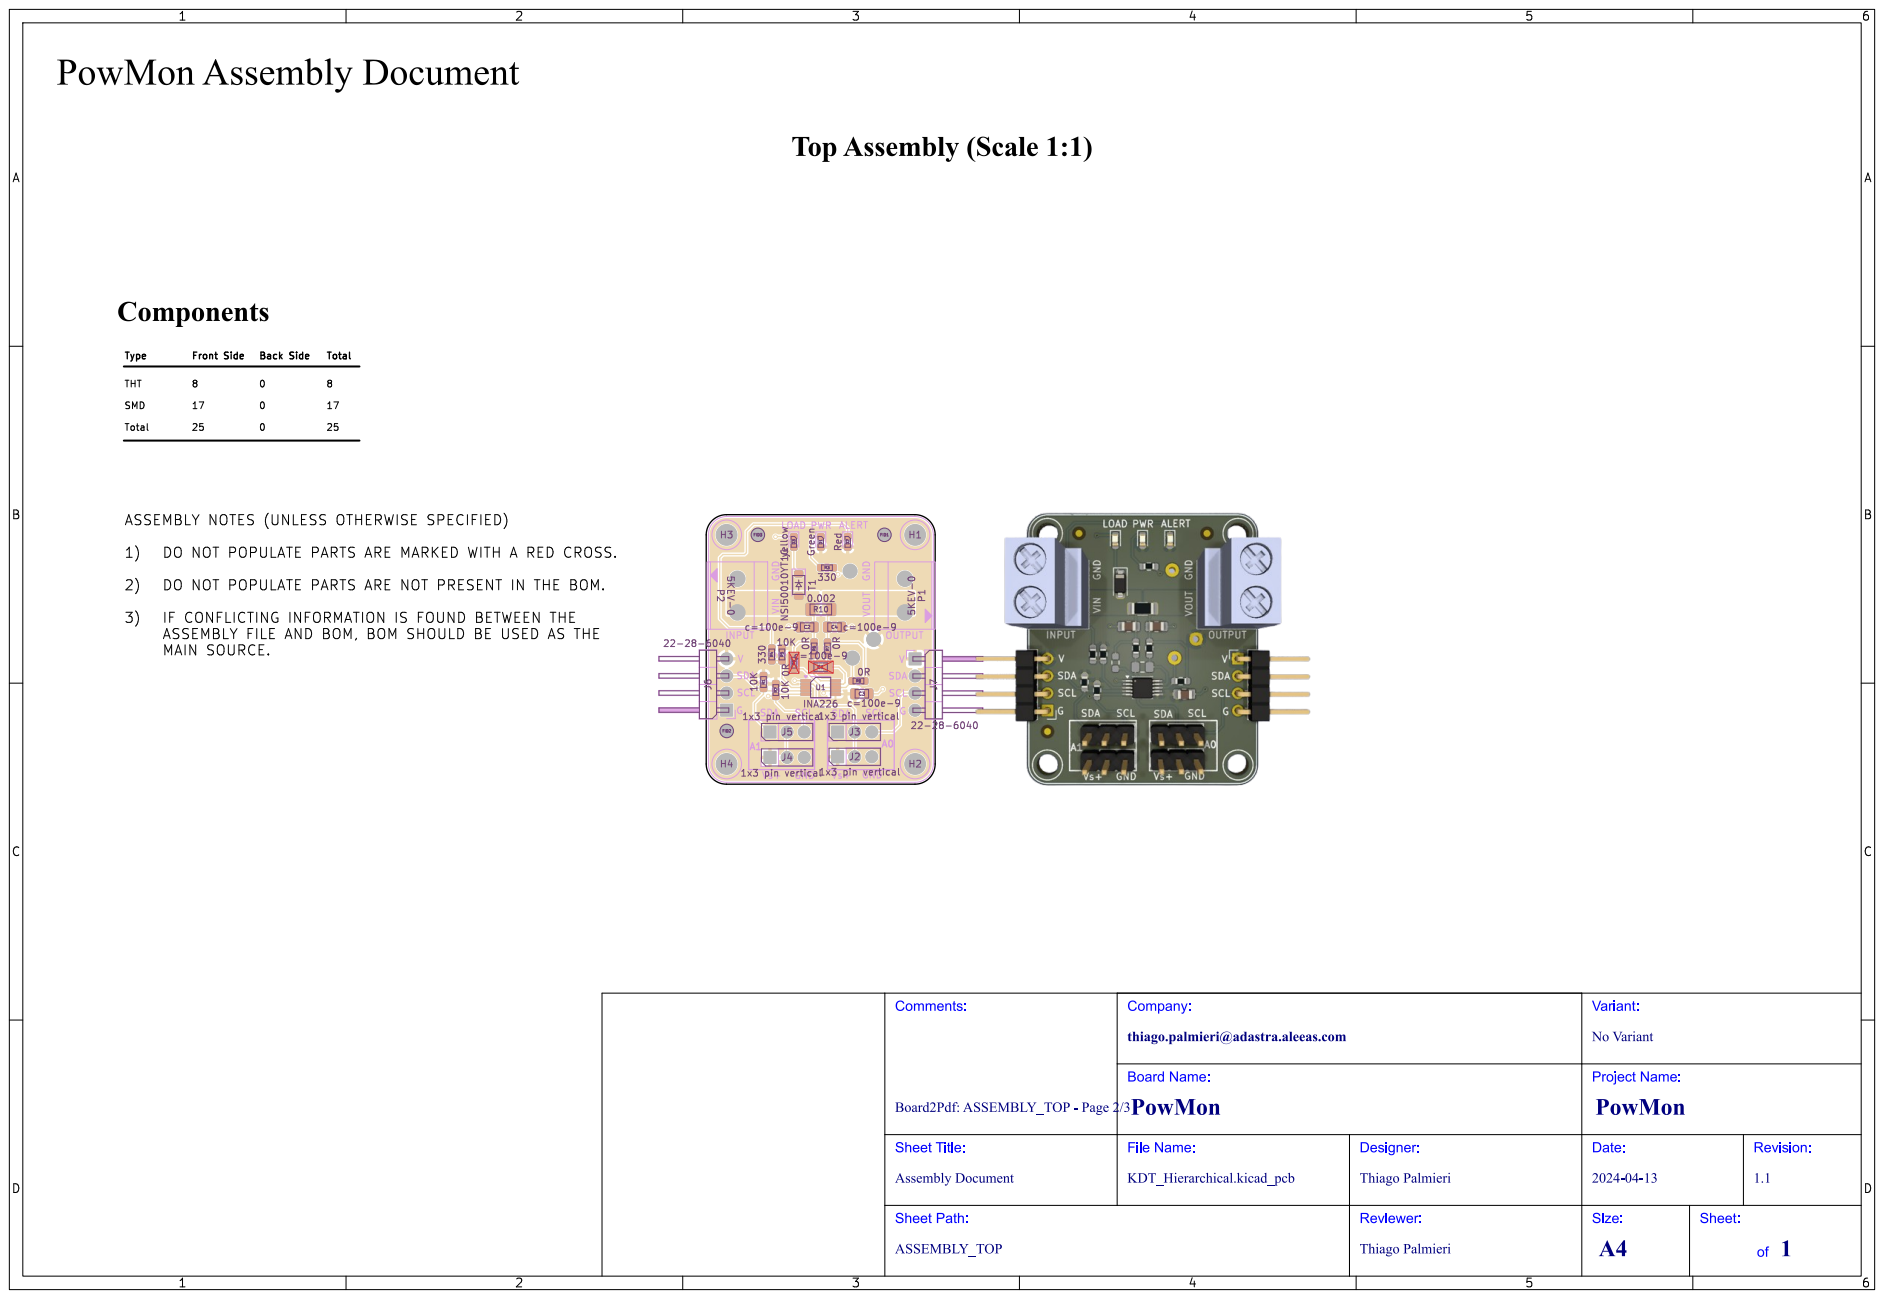
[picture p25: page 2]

Sheet Path: AssemblyDocument Comments: Board2Pdf:ASSEMBLY_TOP- Page2/3 PowMonAssemblyDocument

25 ASSEMBLY NOTES (UNLESS OTHERWISE SPECIFIED)

thiago.palmieri@adastra.aleeas.com

Revision: 1.1 Date: Project Name: 2024-04-13 Reviewer: ThiagoPalmieri Designer:

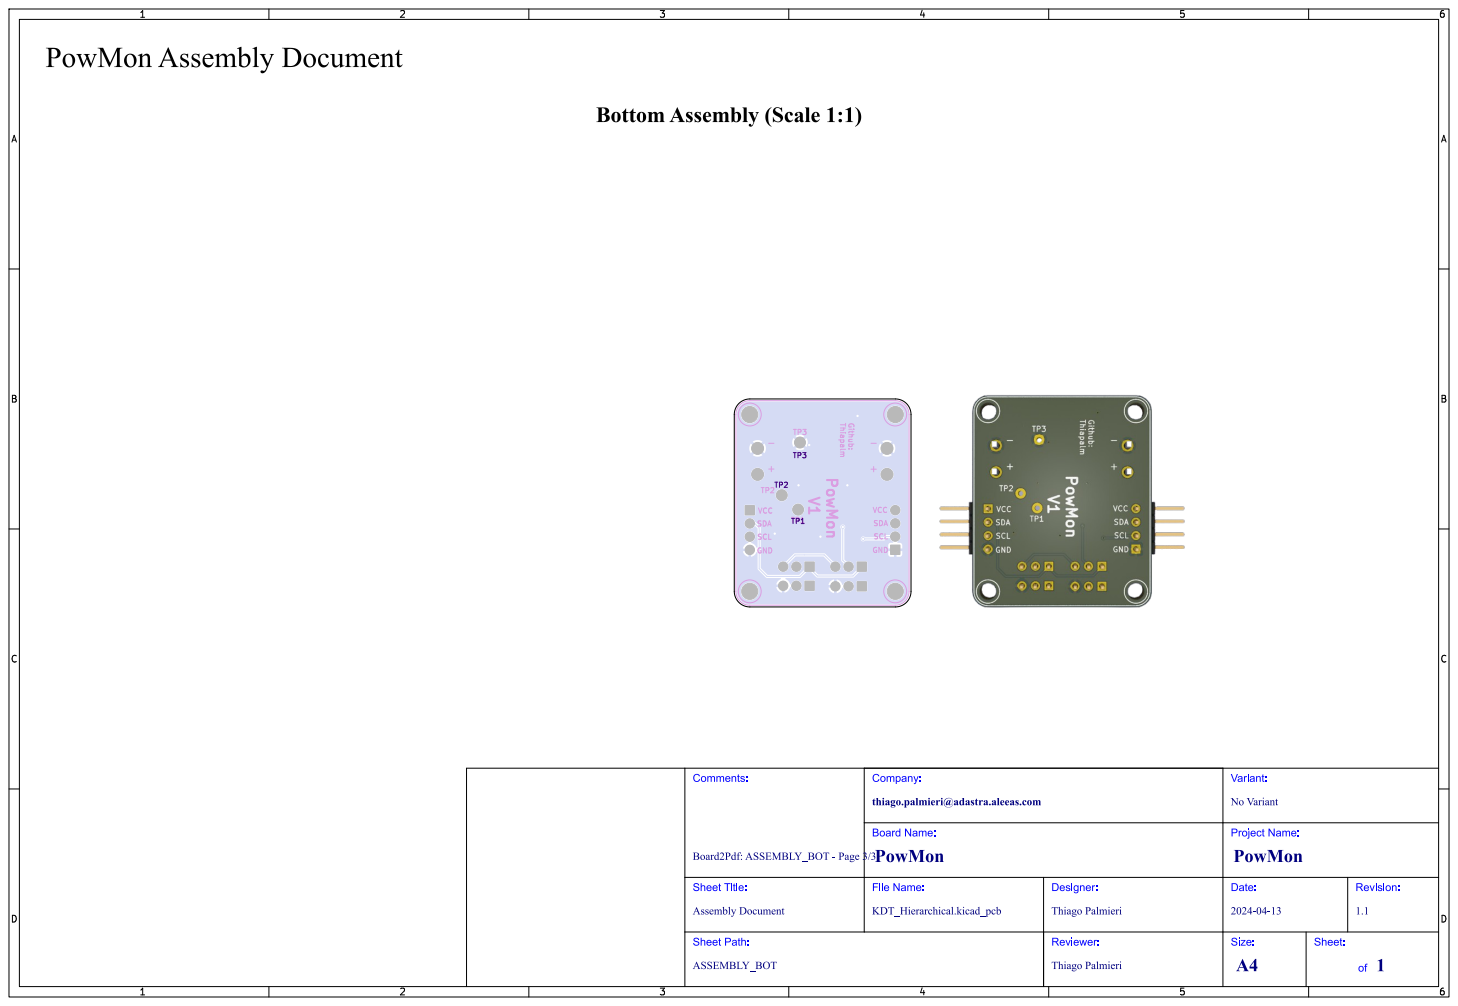
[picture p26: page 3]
SDA; VCC; GND; SCL SDA Thiapalm Github: SCL GND; PowMon; D Sheet: of 1; Size: A4; KDT_Hierarchical.kicad_pcb; ThiagoPalmieri Board Name:; Variant: No Variant Company:; Sheet Title:; File Name: ASSEMBLY_BOT Sheet Path: AssemblyDocument Comments: Board2Pdf:ASSEMBLY_BOT- Page3/3 PowMonAssemblyDocument

thiago.palmieri@adastra.aleeas.com

Revision: 1.1 Date: Project Name: 2024-04-13 Reviewer: ThiagoPalmieri Designer:

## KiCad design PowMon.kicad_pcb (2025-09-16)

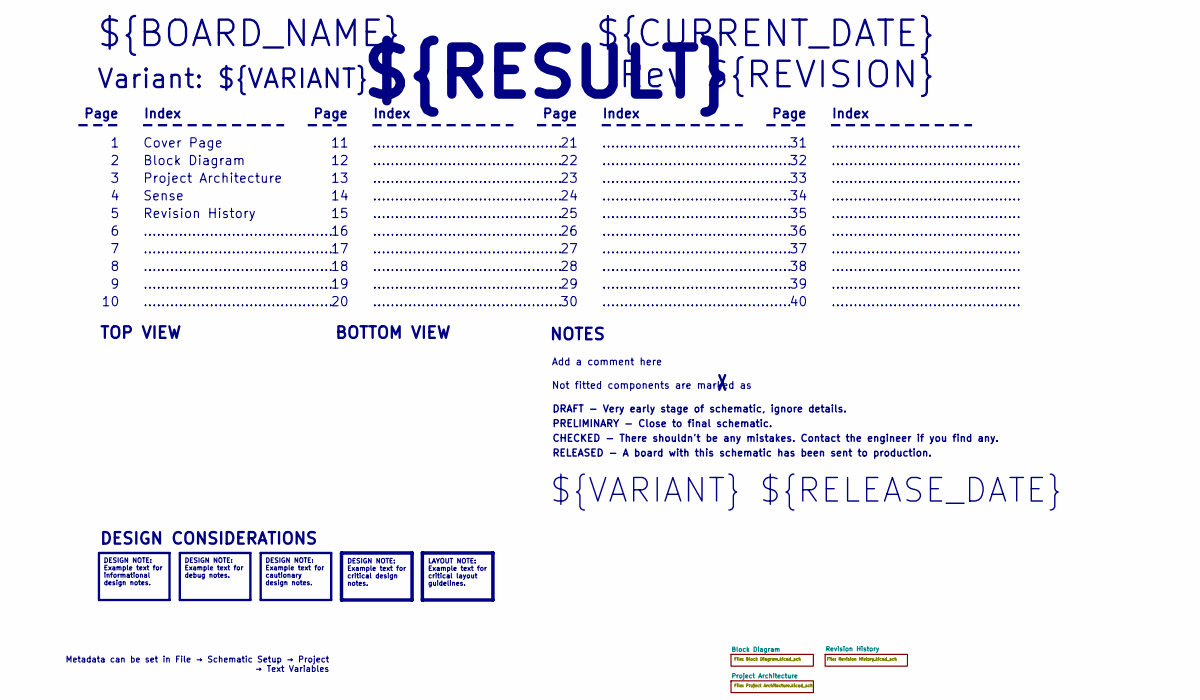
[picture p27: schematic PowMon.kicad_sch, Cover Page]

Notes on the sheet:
BOTTOM VIEW
...........................................
RELEASED - A board with this schematic has been sent to production.
Page
TOP VIEW
Not fitted components are marked as
Index
PRELIMINARY - Close to final schematic.
${VARIANT} ${RELEASE_DATE}
Sense
${CURRENT_DATE}
Variant: ${VARIANT}
Rev ${REVISION}
Revision History
${RESULT}
${BOARD_NAME}
DRAFT - Very early stage of schematic, ignore details.
Block Diagram
Add a comment here
Cover Page
NOTES
Project Architecture
CHECKED - There shouldn't be any mistakes. Contact the engineer if you find any.
DESIGN CONSIDERATIONS
Metadata can be set in File → Schematic Setup → Project → Text Variables
DESIGN NOTE: Example text for informational design notes.
LAYOUT NOTE: Example text for critical layout guidelines.
DESIGN NOTE: Example text for cautionary design notes.
DESIGN NOTE: Example text for debug notes.
DESIGN NOTE: Example text for critical design notes.

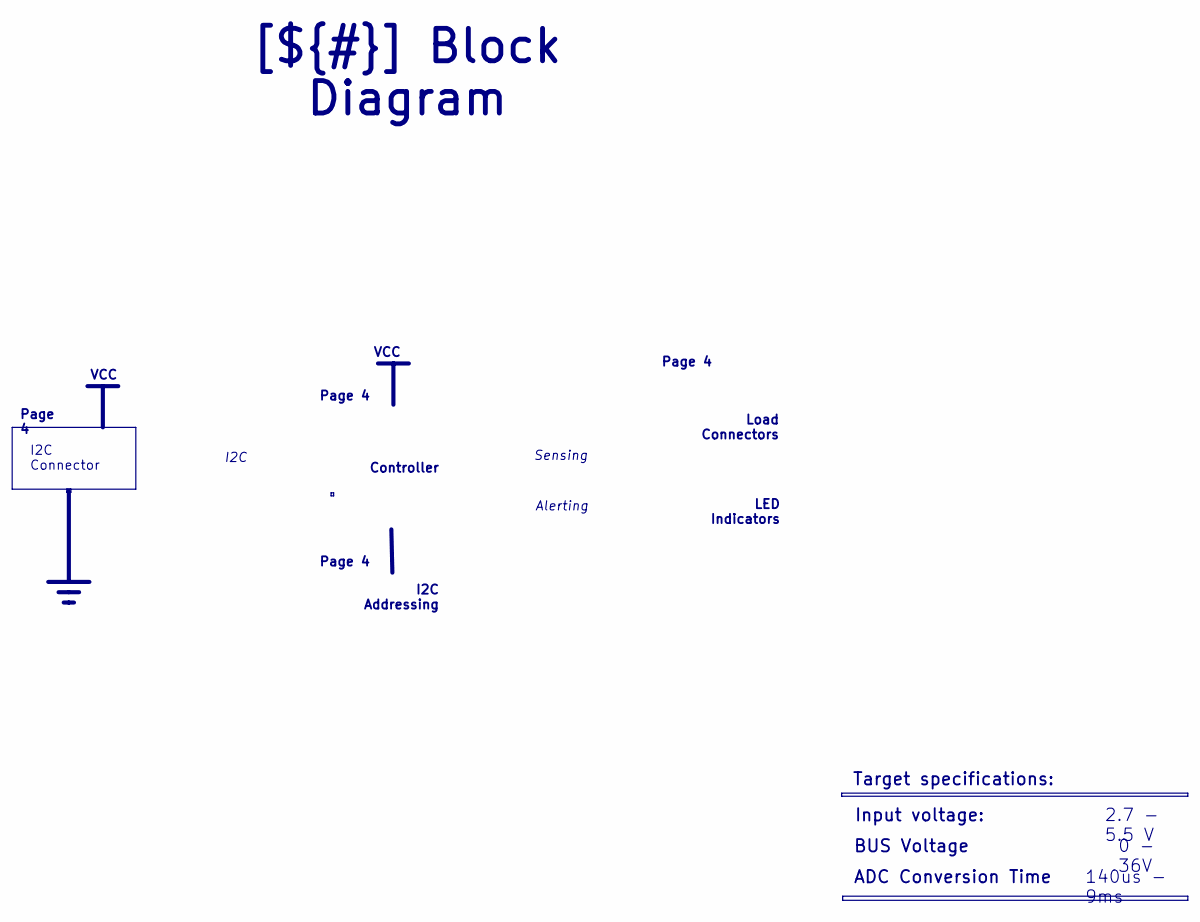
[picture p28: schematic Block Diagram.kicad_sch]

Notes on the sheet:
VCC
ADC Conversion Time
BUS Voltage
I2C
Input voltage:
0 - 36V
I2C Addressing
[${#}] ${TITLE}
Page 4
Target specifications:
140us - 9ms
Load Connectors
2.7 - 5.5 V
Sensing
Alerting
LED Indicators
Controller
I2C Connector

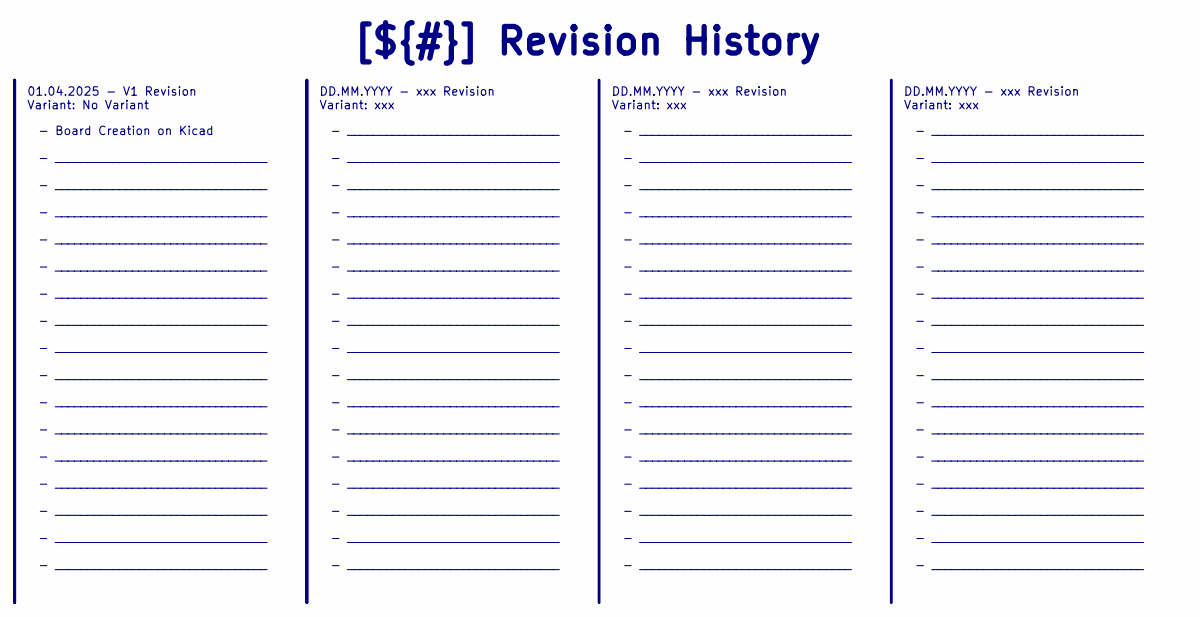
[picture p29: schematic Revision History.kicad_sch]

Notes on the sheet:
- _________________________________ - _________________________________ - _________________________________ - _________________________________ - _________________________________ - _________________________________ - _________________________________ - _________________________________ - _________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
DD.MM.YYYY - xxx Revision Variant: xxx
[${#}] ${TITLE}
- Board Creation on Kicad - _________________________________ - _________________________________ - _________________________________ - _________________________________ - _________________________________ - _________________________________ - _________________________________ - ___________________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
01.04.2025 - V1 Revision Variant: No Variant

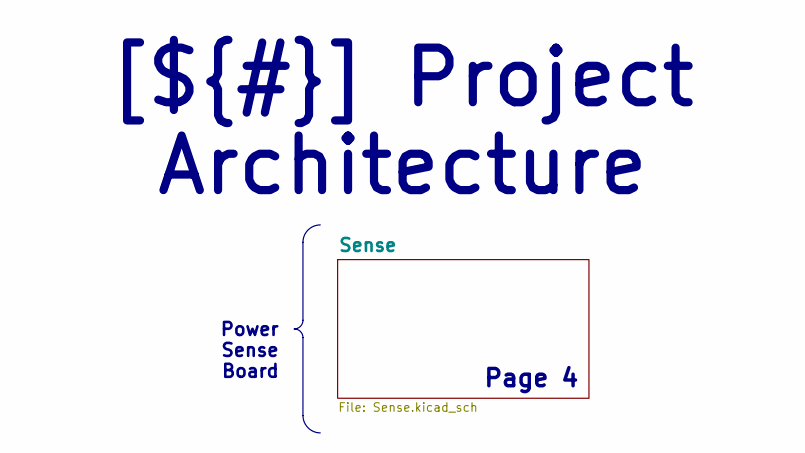
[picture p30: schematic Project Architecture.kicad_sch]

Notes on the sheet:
Page 4
Power Sense Board
[${#}] ${TITLE}

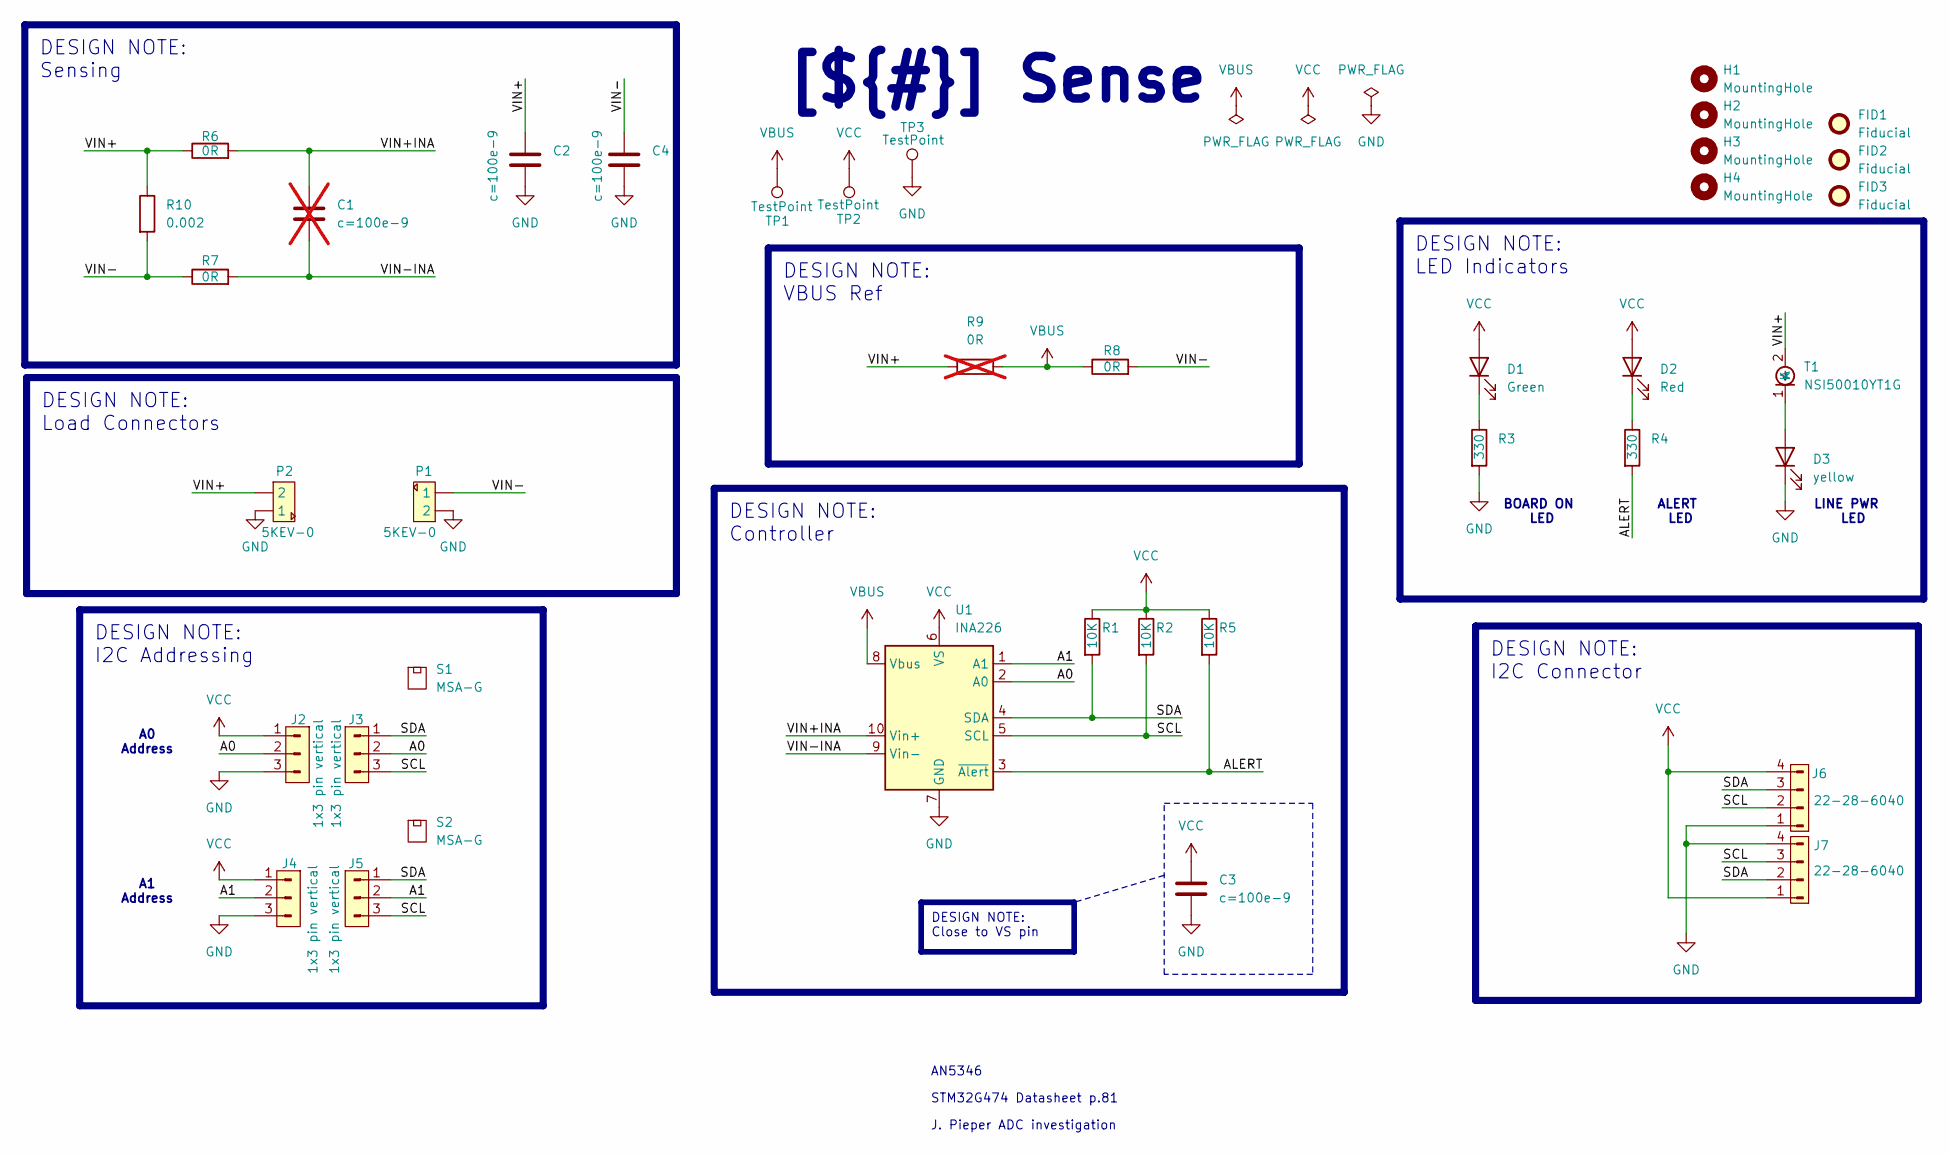
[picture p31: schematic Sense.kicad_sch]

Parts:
C1: c=100e-9; C_0805_2012Metric_Pad1.18x1.45mm_HandSolder; Manufacturer Part Number 0805B104K500CT; not fitted
C2, C3, C4: c=100e-9; C_0805_2012Metric_Pad1.18x1.45mm_HandSolder; Manufacturer Part Number 0805B104K500CT
D1: Green; LED_0603_1608Metric; Manufacturer Part Number SML-LX0603GW-TR
D2: Red; LED_0603_1608Metric; Manufacturer Part Number SM0603SRC
D3: yellow; LED_0603_1608Metric; Manufacturer Part Number LTST-C191KSKT
FID1, FID2, FID3: Fiducial; Fiducial_1mm_Mask2mm
H1, H2, H3, H4: MountingHole; MountingHole_3mm
J2, J3, J4, J5: 1x3 pin vertical; PinHeader_1x03_P2.54mm_Vertical; Manufacturer Part Number G800LR305018EU
J6, J7: 22-28-6040; PinHeader_1x04_P2.54mm_Horizontal; Manufacturer Part Number 22-28-6040
P1, P2: 5KEV-0; Terminal Block 5mm; Manufacturer Part Number 5KEV-0
R1, R2, R5: 10K; R_0603_1608Metric_Pad0.98x0.95mm_HandSolder; Manufacturer Part Number CRCW060333R0FKEA
R3, R4: 330; R_0603_1608Metric_Pad0.98x0.95mm_HandSolder; Manufacturer Part Number ERJ-3GEYJ331V
R6, R7, R8: 0R; R_0603_1608Metric_Pad0.98x0.95mm_HandSolder; Manufacturer Part Number CRCW06030000Z0EI
R9: 0R; R_0603_1608Metric_Pad0.98x0.95mm_HandSolder; Manufacturer Part Number CRCW06030000Z0EI; not fitted
R10: 0.002; R_1206_3216Metric_Pad1.30x1.75mm_HandSolder; Manufacturer Part Number WSL12062L000FEA
S1, S2: MSA-G; Manufacturer Part Number MSA-G
T1: NSI50010YT1G; D_SOD-123; Manufacturer Part Number NSI50010YT1G
TP1, TP2, TP3: TestPoint; TestPoint_PTH_1mm_2mm
U1: INA226; VSSOP-10_3x3mm_P0.5mm; Manufacturer Part Number INA226AIDGST

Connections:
/Project Architecture/Sense/A0: J2.2, J3.2, U1.2 (A0)
/Project Architecture/Sense/A1: J4.2, J5.2, U1.1 (A1)
/Project Architecture/Sense/ALERT: R4.2, R5.2, U1.3 (~Alert)
/Project Architecture/Sense/SCL: J3.3, J5.3, J6.2, J7.3, R2.2, U1.5 (SCL)
/Project Architecture/Sense/SDA: J3.1, J5.1, J6.3, J7.2, R1.2, U1.4 (SDA)
/Project Architecture/Sense/VIN+: C2.1, P2.2, R6.1, R9.1, R10.1, T1.2 (A)
/Project Architecture/Sense/VIN+INA: C1.2, R6.2, U1.10 (Vin+)
/Project Architecture/Sense/VIN-: C4.1, P1.1, R7.1, R8.2, R10.2
/Project Architecture/Sense/VIN-INA: C1.1, R7.2, U1.9 (Vin-)
GND: C2.2, C3.1, C4.2, D3.1 (K), J2.3, J4.3, J6.1, J7.4, P1.2, P2.1, R3.2, TP3.1, U1.7 (GND)
unnamed: D1.1 (K), R3.1
unnamed: D2.1 (K), R4.1
unnamed: D3.2 (A), T1.1 (K)
VBUS: R8.1, R9.2, TP1.1, U1.8 (Vbus)
VCC: C3.2, D1.2 (A), D2.2 (A), J2.1, J4.1, J6.4, J7.1, R1.1, R2.1, R5.1, TP2.1, U1.6 (VS)

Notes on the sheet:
A0 Address
ALERT LED
BOARD ON LED
J. Pieper ADC investigation
A1 Address
STM32G474 Datasheet p.81
AN5346
LINE PWR LED
DESIGN NOTE: LED Indicators
DESIGN NOTE: I2C Connector
DESIGN NOTE: Controller
DESIGN NOTE: I2C Addressing
[${#}] ${TITLE}
DESIGN NOTE: Load Connectors
DESIGN NOTE: VBUS Ref
DESIGN NOTE: Close to VS pin
DESIGN NOTE: Sensing

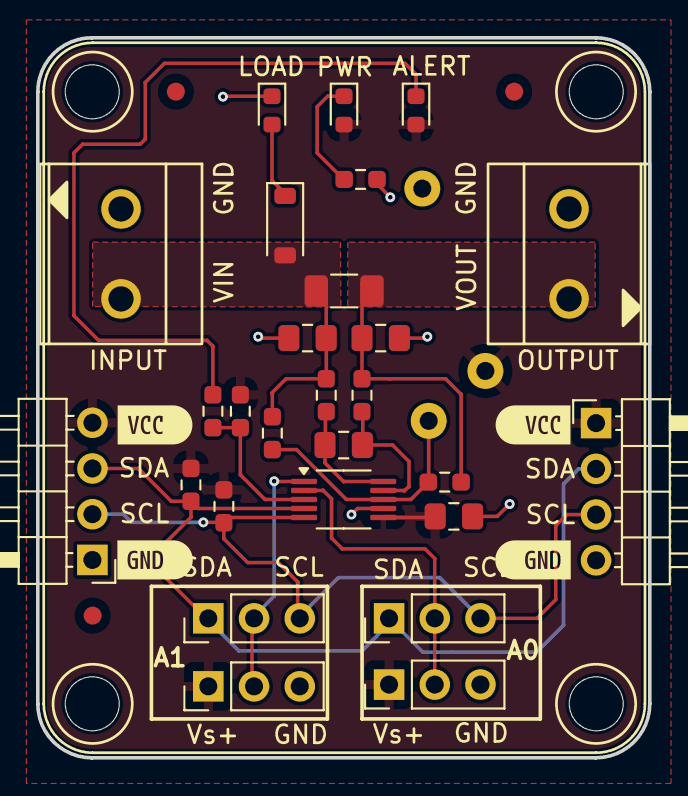
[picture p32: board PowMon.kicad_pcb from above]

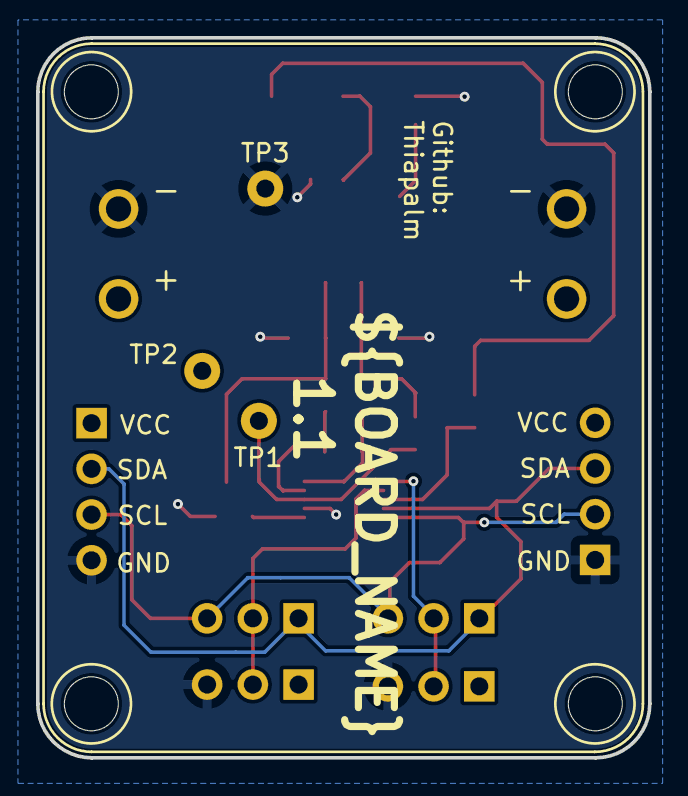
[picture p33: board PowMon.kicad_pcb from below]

Board: 2 copper layers, 34.0 x 40.0 mm, 41 parts (3 on the bottom side), 15 nets.

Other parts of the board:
kibuzzard-67FD642C: G***; kibuzzard-67FD642C
kibuzzard-67FD645D: G***; kibuzzard-67FD645D
kibuzzard-67FD646E: G***; kibuzzard-67FD646E
kibuzzard-67FD6413: G***; kibuzzard-67FD6413

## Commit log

2025-03-31 Changed sense resistor and fixed connector position
    [KDT_Hierarchical.kicad_pcb, Sense.kicad_sch]
2025-03-31 Changed resistor position
    [Block Diagram.kicad_sch, KDT_Hierarchical.kicad_pcb, Sense.kicad_sch]
2025-04-01 Split I2C connector
    [Block Diagram.kicad_sch, KDT_Hierarchical.kicad_pcb, Sense.kicad_sch]
2025-04-01 Outputs generated, ready for prototyping
    [Block Diagram.kicad_sch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]
2025-04-07 fixed component positions
    [KDT_Hierarchical-B_Mask.gbr, KDT_Hierarchical-B_Paste.gbr, KDT_Hierarchical-B_Silkscreen.gbr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]
2025-04-07 Fixed file names
    [PowMon-B_Mask.gbr, PowMon-B_Paste.gbr, PowMon-B_Silkscreen.gbr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]
2025-04-08 Added FreeCad made enclosure
    [PowMonBox-BottomBody.stl, PowMonBox-TopBody.stl, PowMonBox.FCStd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]
2025-08-29 Intermediary save
    [PowMon.kicad_pcb, PowMonBox.FCStd]

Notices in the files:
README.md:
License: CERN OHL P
